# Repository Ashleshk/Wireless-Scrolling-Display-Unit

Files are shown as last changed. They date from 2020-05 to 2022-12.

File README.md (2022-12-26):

# Wireless-Scrolling-Display-Unit
 This project was buit for Academic Evaluation of term work for the Third year Mini Project  building in the subject of Electronic Sensor & Mini-Project in Course of E&TC 

## Working Project
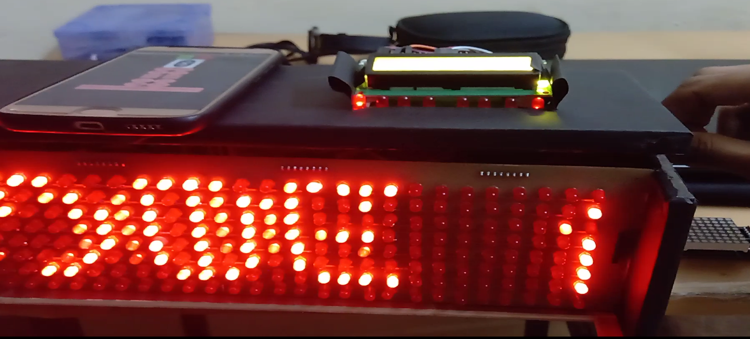
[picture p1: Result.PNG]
Result


## Won Project Exhibition Competition 
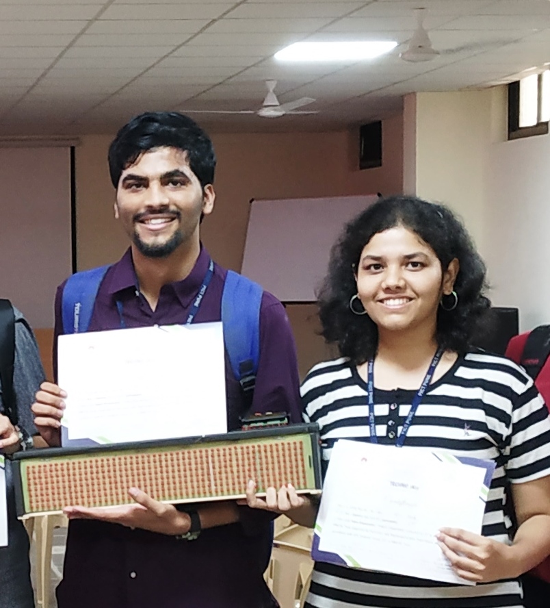
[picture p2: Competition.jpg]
Achivement


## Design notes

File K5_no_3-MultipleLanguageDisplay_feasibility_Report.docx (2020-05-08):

Title : Multiple Language Display Unit (Wireless Display Unit)

……………………………………………………………………………………………………………………………………………………………..

Group members: 1) Ashlesh Khajbage ………………2) Aditi Dorle …………………………………………………

3) Akhil Rane …………..……………………………………. 4)…………………………………………………………………….

Tools required | Testing possibility | Controller | Cost
Hardware/components LEDs Bluetooth Module / ESP2866 MAX7219 Resistors Perforated Board | Hardware Yes Yes Yes Yes No(unless clock input req) No No | Arduino Or PIC18F4550 (whichever support communication feasible) | ESP2866 – 200/- Boards,LEDs- 260/- MAX7219(6) -1080/- Resistors -6/- SolderingWire-80/- Wire -36/-
Software - MATLAB IDE - Arduino IDE - Proteus - Eagle - Fusion 360 | Software Yes yes yes yes (at least on 1 pc)
Tools available within campus or outside | Sensors required | Signal conditioning if any
-Soldering gun -dc power supply unit | -nil | -3.3V signal Conditioning OR -separate power supply | - 50/-
Applications if any | PCB design and fabrication | Datasheets/ application notes available
- Railway stations, - Airports - Colleges And Schools - Bus-stops and any other public places. - Public transport | - Controller circuit - Led Matrix - Power supply (5V and 3.3V) - Daughter Board | - Arduino/PIC18F - Decade counter(4017) - Transistors (2N3904) - MAX7219 | Estimated Cost Led matrix -1500/- Max-driver – 360/- Arduino board- 400/-
Mechanical design | Enclosure design | Demonstration
- Rectangular Box Signature of Guide | - Wooden Enclosure

Pune Institute of Computer technology, Pune Department of Electronics and Telecommunication T. E Mini project feasibility study sheet Sem-II 2018-19

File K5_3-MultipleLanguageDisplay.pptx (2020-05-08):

## Pune Institute of Computer Technology, Pune Dept. of E&TC

304196: Employability Skills and Mini Project (ESMP)
(2015 Course)

“MULTIPLE LANGUAGE
DISPLAY UNIT”

Guided By: Dr. R.Sreemathy

By:
1) ADITI DORLE (3503)
2) AKHIL RANE(3506)
3) ASHLESH KHAJBAGE(3508)

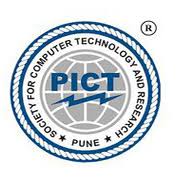
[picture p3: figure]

## Block Schematic

TE <Class>

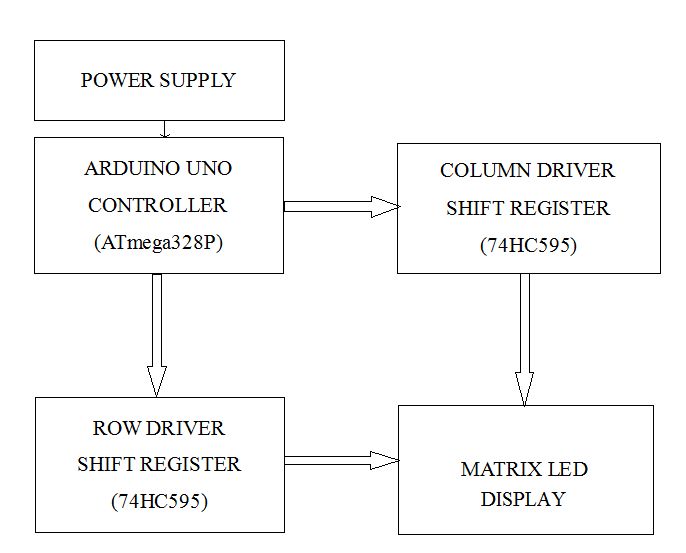
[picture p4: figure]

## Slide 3

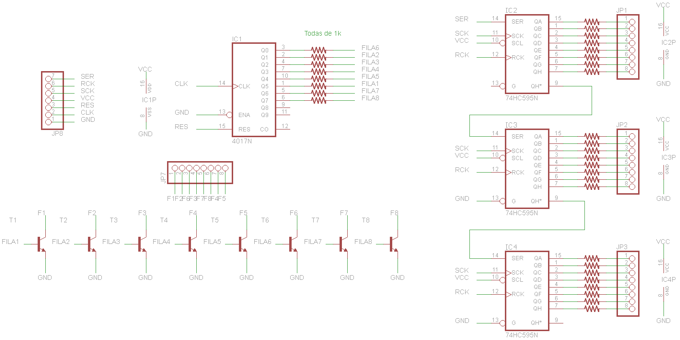
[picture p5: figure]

## resources Required

- 144 RED LEDs.
- 24 Resistors
- 4017 Decade Counter
- 6 1k-Resistances
- 6 2N3904 Transistors
- A Long Perf Board
- Arduino356
- 3 74HC595 shift register
- Some pin headers

## Working model Animation

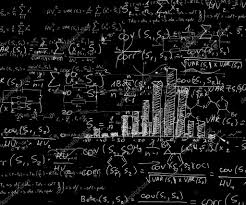
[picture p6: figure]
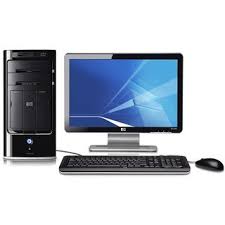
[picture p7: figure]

Input: Satyamev Jayte

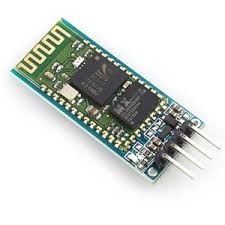
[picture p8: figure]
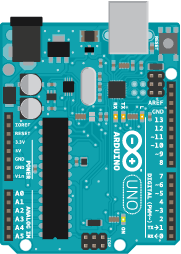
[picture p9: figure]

Satyamev Jayte

सत्यमेव जयते

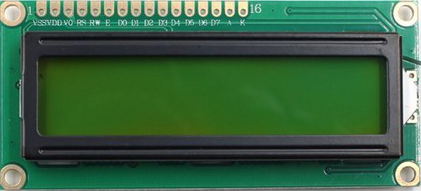
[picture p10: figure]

String recieving

Bluetooth device

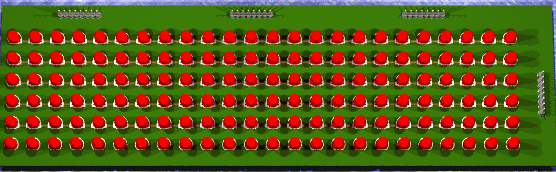
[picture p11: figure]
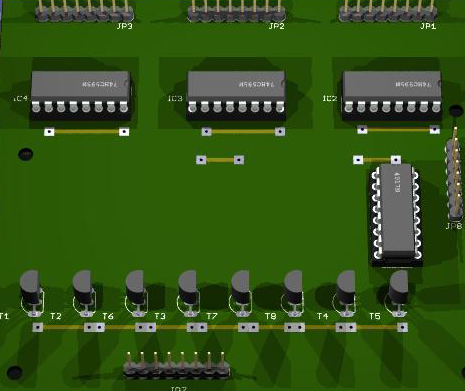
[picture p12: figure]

Connected

Satyamev Jayte

सत्यमेव जयते

## Features, future Scope

- This project focuses on displaying messages of multiple languages.
- It is cost effective.
- Easy to build.
- It can be used in
  - Railway stations,
  - Airports
  - Colleges And Schools
  - Bus-stops and any other public places.
  - Public transport

## References

- Research paper:
  - Design & Simulation of Moving Message Display using Microcontroller: Available from: https://www.researchgate.net/ (https://www.researchgate.net/publication/)
publication/ (https://www.researchgate.net/publication/)[Accessed: 10th May 2010]
- Website References:
  - Electronics LAB, Santi Rodríguez: 24x6 led matrix control unit[online]. Available from: http://www.electronics-lab.com/project/24x6-led-matrix-control-circuit/ (http://www.electronics-lab.com/project/24x6-led-matrix-control-circuit/)
  - Intructables, karthimech09 (https://www.instructables.com/member/karthimech09/) : 48x8 Scrolling matrix Display using arduino [online]. Available from: https://www.instructables.com/id/Make-a-24X6-LED-matrix/

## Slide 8

Thanks

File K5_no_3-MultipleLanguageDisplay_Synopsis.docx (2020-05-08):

Employability Skills& Mini Project
Class & Batch | | : | TE-5; K5 | | Group No. | | : | 3

Synopsis

on

“MULTIPLE LANGUAGE DISPLAY UNIT”

Submitted By
Roll No. | Name of the Student | | | e-mail id | | Mobile No.
3503 | Aditi Dorle | | | dorle.aditi@gmail.com | | 7743876151
3506 | Akhil Rane | | | ar.federer@gmail.com | | 9604780239
3508 | Ashlesh Khajbage | | | ashleshuk@gmail.com | | 9168003015

Project Guide:

Dr. R. Sreemati

DEPARTMENT OF ELECTRONICS AND TELECOMMUNICATIONS

PUNE INSTITUTE OF COMPUTER TECHNOLOGY

Academic Year : 2018 - 2019

1. Project Title: MULTIPLE LANGUAGE DISPLAY UNIT.

2. Introduction/ Motivation :

Why is the name board in railway stations written in three languages? As Railways falls under the Ministry of Railways of the Central Government, it follows the above two articles of the Constitution of India. Hence for the spread of Hindi as the Official Language (Raajbhasha), All stations display name boards in three languages i.e. English, Hindi and the official language of the state. The Same is with the case of bus stations, airports, locals trains, and buses etc. the displays used to announce the arrival and departure of a particular train, bus. There are many such displays used at a time on these stations. These displays are also used to display various other important messages like if someone’s missing if anyone has lost their belongings, which part of the stations the entire schedule can be seen, etc. Hence, such displays are usually called PLATFORM DISPLAYS.

These displays are mainly made up of an LED- matrix. The LED-matrix consists of many LEDs grouped together to form a matrix and is controlled through a control unit and a controller. This matrix mainly displays the messages pre-stored or short messages which can be instantly displayed from an interface for a certain amount of time. The led-matrix can be of 24x8 LEDs. It will be a sliding display, which will display words or messages (characters and numbers) in Hindi or English language.

3. Literature Survey / Prior work :

In earlier times when bus and railway stations were not developed and people had to find out time and wait hours for their buses and trains to arrive. There used to be pre-scheduled printed boards of arrival and departure of trains and buses. Then there used to be simple announcements through microphones and loudspeakers explaining the time of arrival and departure or the delay of the trains. Also, the driver has to yell about the next stop. But as the technology grew, platform displays came into existence. People could now read as to when their train will arrive. Since there are people from different linguistic backgrounds in India, there is a need for multiple language displays. The first platform displays were set in Britain and later on adapted worldwide. This project is just an extension of platform displays with additional benefits.

4. Problem Definition and Objectives :

The project will consist of an LED-MATRIX (24X8) which will be used to display the short and concise messages. The LED-MATRIX will be controlled using a control circuit/module and a controller. The major objective of this project is that in a place like India, where different people speak and understand different languages we need to account to their needs. The messages are after all displayed for the people’s benefit. So, everyone should be able to understand displayed messages easily, hence this concept of different language display.

5. Objectives :

1. Multiple languages to be displayed: Hindi, English.

2. Self-made LED MATRIX.

3. 24x8 LED MATRIX

1.Block Diagram :


1. Power Supply - Through the Power Supply, we'll provide 5V and 3.3V for the microcontroller board and communication module that may be wifi module or a Bluetooth module.

2. PIC microcontroller- The PIC stands for Peripheral Interface Controller. The microcontroller generates the output logic pulses so that the LED light is switched ON and OFF at certain intervals. The Crystal interfaced to the input pins of the microcontroller provides accurate clock signals at the crystal frequency.

3.Control Unit-The circuit is able to drive a 24×8 LED matrix using an external Microcontroller. Control signals can be easily generated by a microcontroller.

4 LED Matrix- In a dot matrix display, multiple LEDs are wired together in rows and columns. This is done to minimize the number of pins required to drive them. For example, an 8×8 matrix of LEDs (shown below) would need 64 I/O pins, one for each LED pixel. By wiring all the anodes together in rows (R1 through R8), and cathodes in columns (C1 through C8), the required number of I/O pins is reduced to 16. Each LED is addressed by its row and column number.

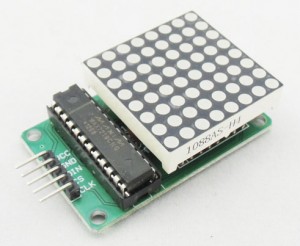
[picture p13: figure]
Pre-wired MAX 7219 and 8 x 8 LED matrix
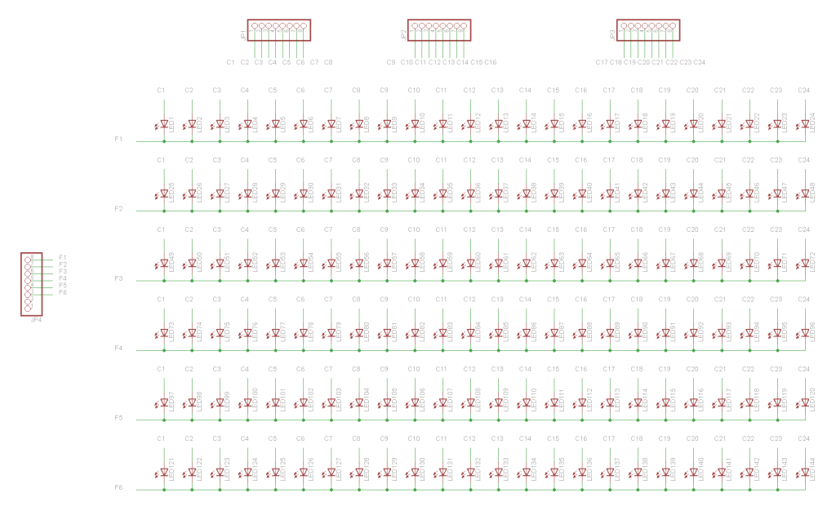
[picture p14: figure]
LED_board_schematic

2. Hardware Requirements:
1. LEDS
2. SHIFT REGISTERS
3. RESISTORS
4. DECADE COUNTERS
5. WIFI / BLUETOOTH MODULE
6. DC POWER SUPPLY
7. MICROCONTROLLER
8. USB-to-SERIAL CONVERTER
3. Software Requirements:
1. MPLAB/ARDUINO/PUTTY
2. PROTEUS
3. EAGLE
4. References
i. Electronics LAB, Santi Rodríguez: 24x6 led matrix control unit[online]. Available from: http://www.electronics-lab.com/project/24x6-led-matrix-control-circuit/
ii. Intructables, karthimech09 (https://www.instructables.com/member/karthimech09/) : 48x8 Scrolling matrix Display using arduino [online]. Available from: (http://www.electronics-lab.com/project/24x6-led-matrix-control-circuit/) https://www.instructables.com/id/Make-a-24X6-LED-matrix/

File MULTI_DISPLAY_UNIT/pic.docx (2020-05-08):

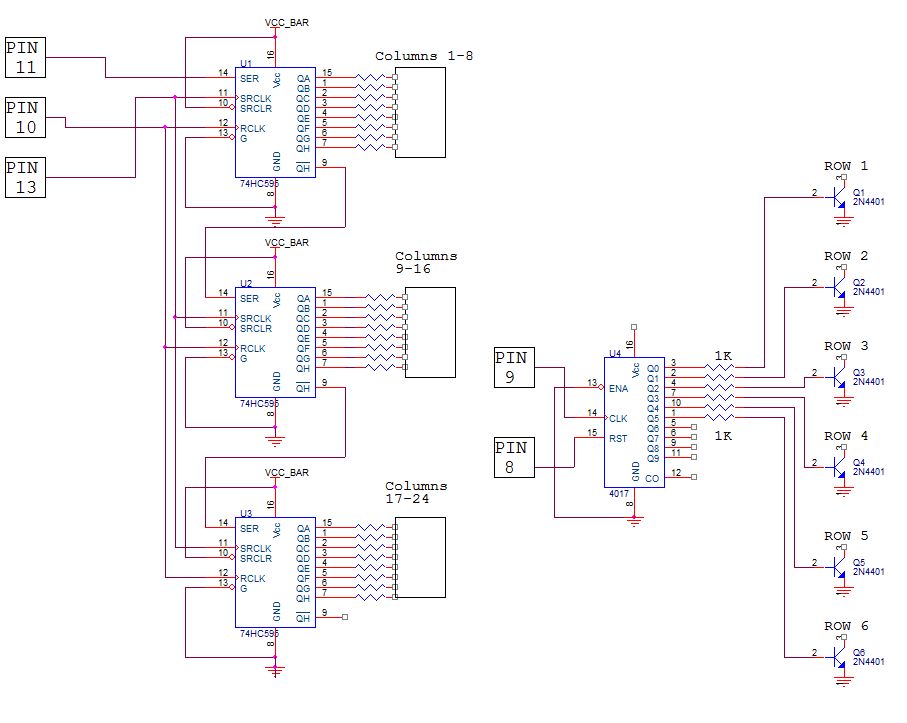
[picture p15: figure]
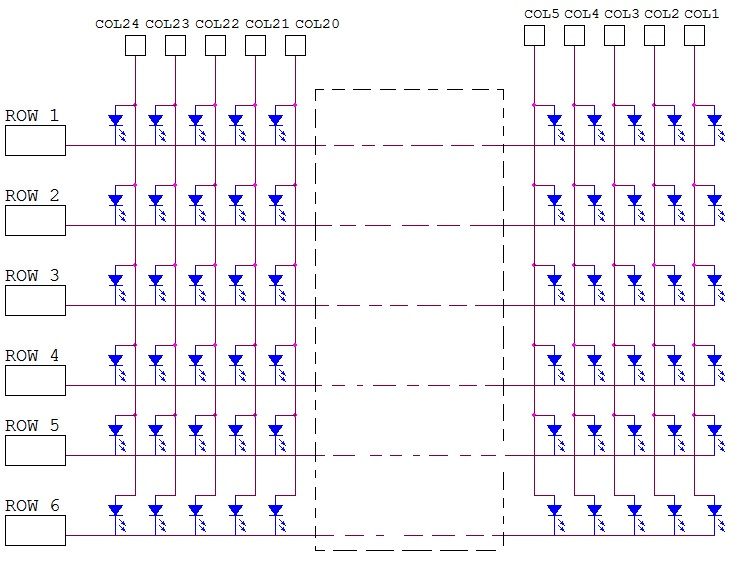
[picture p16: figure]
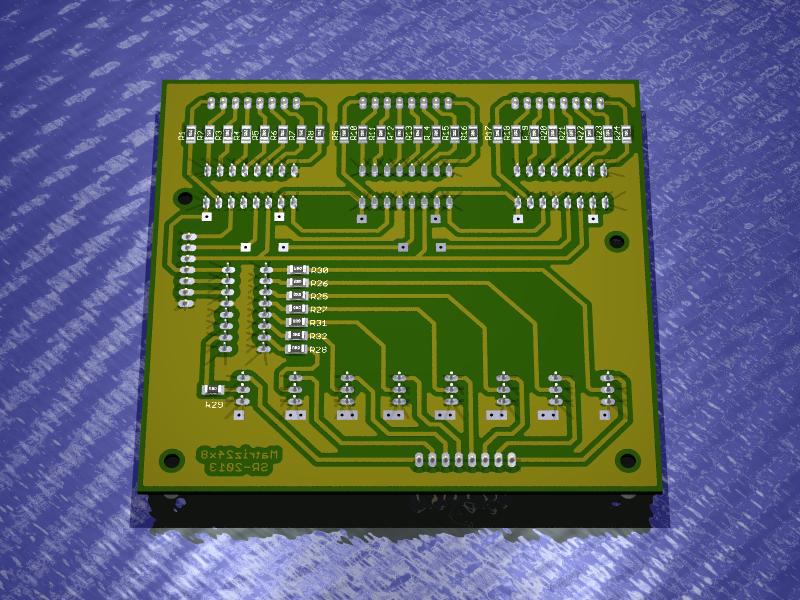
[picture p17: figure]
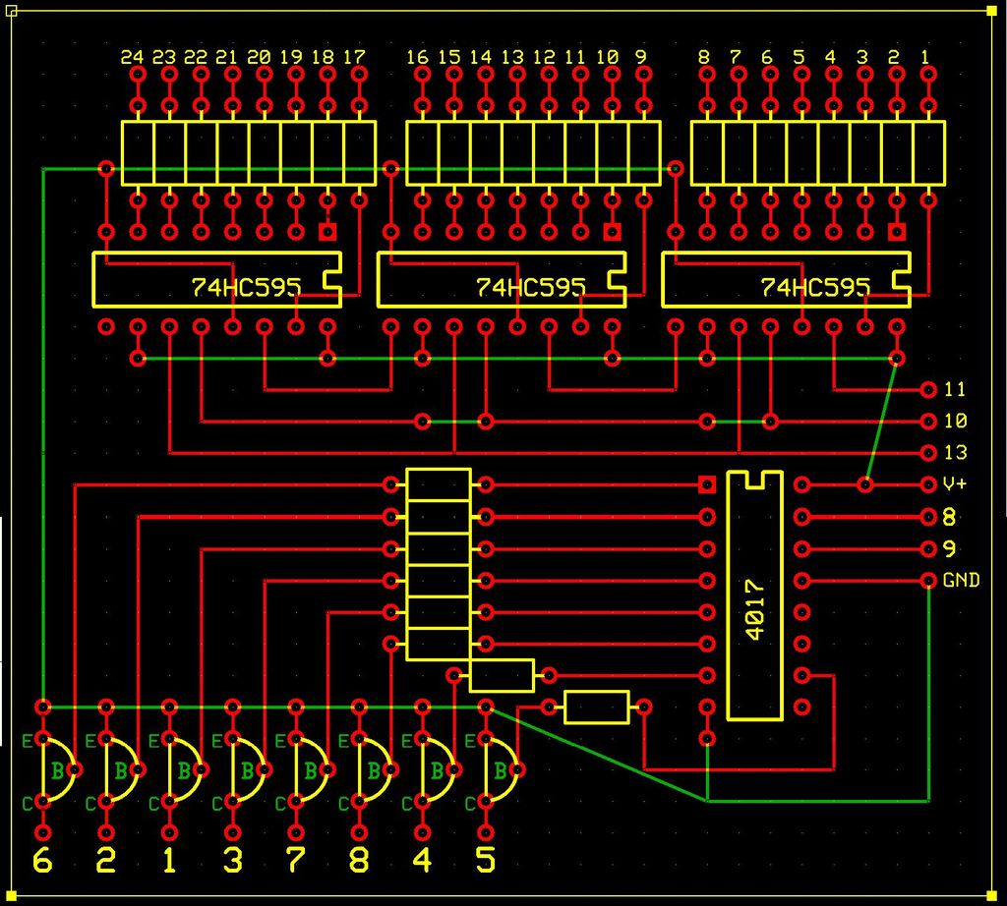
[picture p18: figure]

267.97 x 83.82mm and control board size: 100.33 x 93.65mm

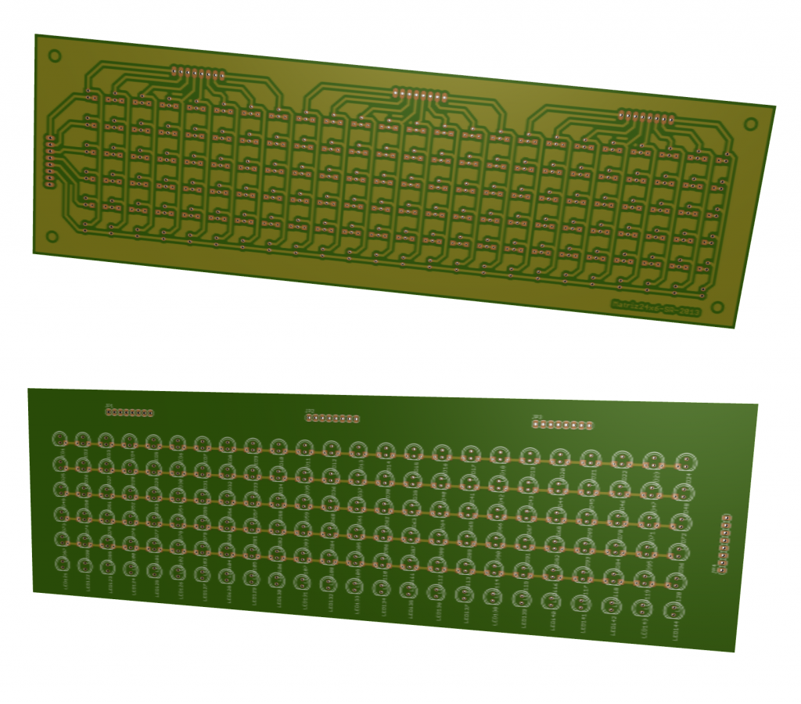
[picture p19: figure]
3D_LED_board_PCB
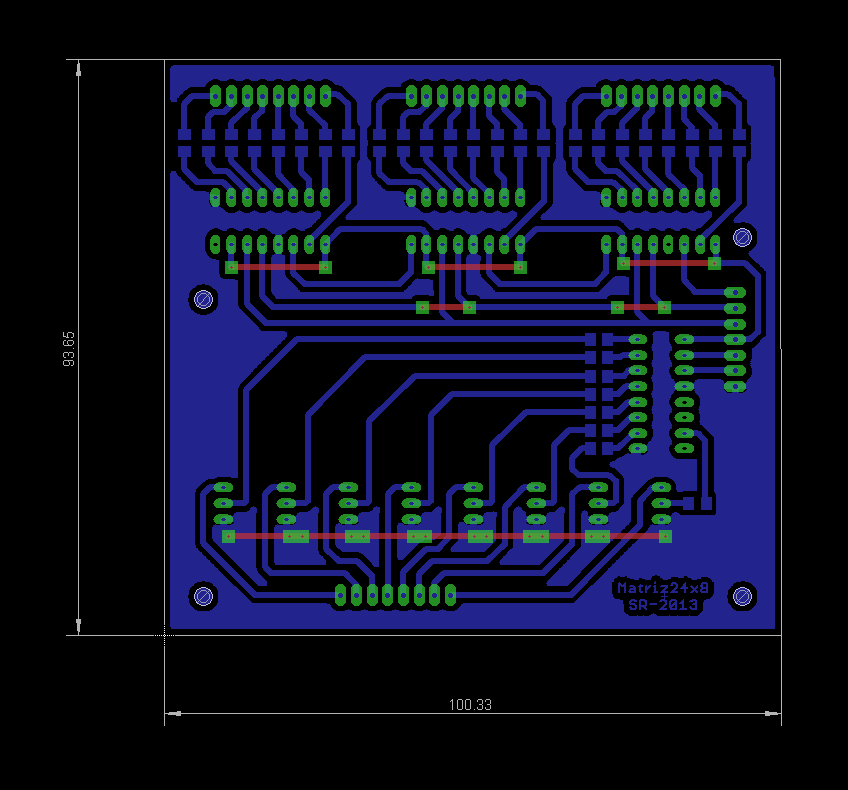
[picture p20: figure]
LED_board_schematic
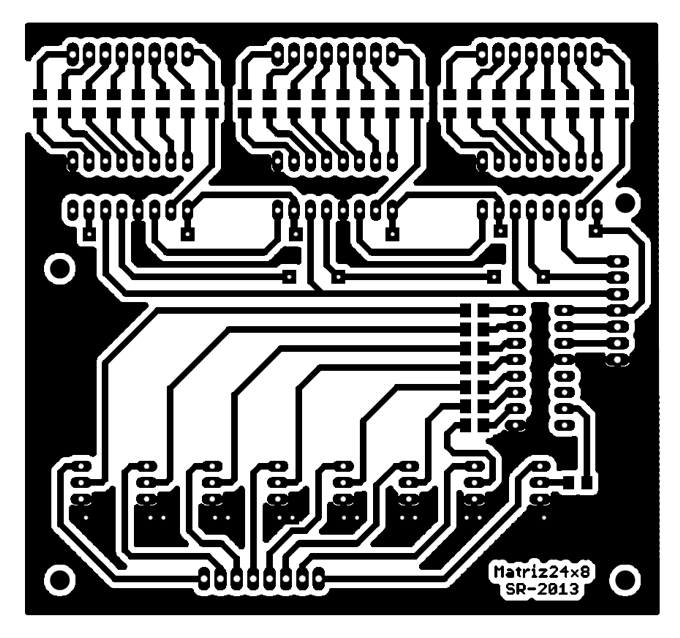
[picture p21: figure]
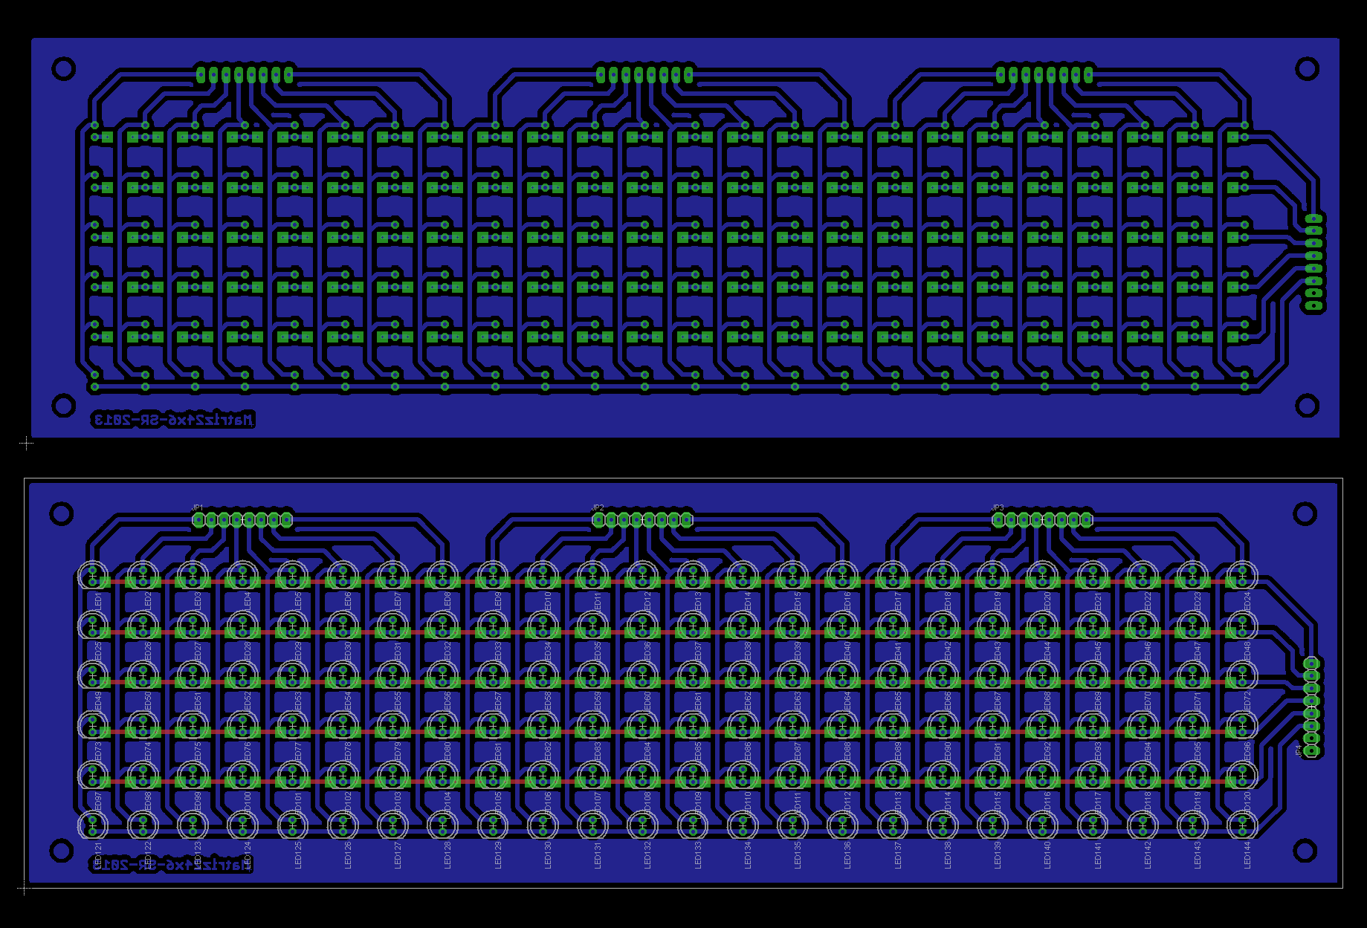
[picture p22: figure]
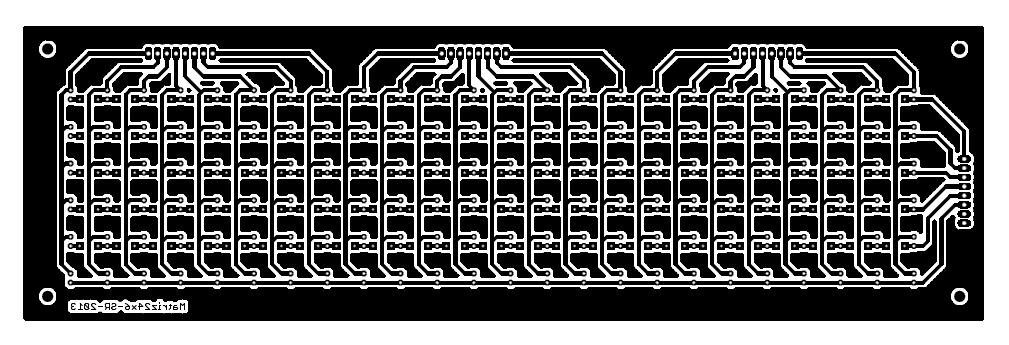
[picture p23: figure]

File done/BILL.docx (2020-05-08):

Sr. No | Component Name | Quantity | Per Unit Cost | Cost (Rupees)
1 | ATMEGA 328 PU | 1 | 300 | 300
2 | LEDS | 500 | 0.8 | 400
3 | PERF BOARD | 2 | 50 | 100
4 | SOLDER WIRE | 1 | 80 | 80
5 | WIRE | 15 | 5 | 75
6 | PINHEADS | 4 | 20 | 81
7 | MAX 7219 | 6 | 180 | 1080
8 | Capacitor 22uF | 2 | 10 | 20
9 | Capacitor 10uF | 2 | 15 | 30
10 | Capacitor disc | 3 | 10 | 30
11 | JUMPER WIRES | 2 | 80 | 160
12 | ATMEGA BASE | 1 | 10 | 10
13 | RESISTOR 150 Ohm | 4 | 1 | 4
14 | RESISTOR 10k Ohm | 1 | 2 | 2
15 | CRYSTAL OSCILLATOR | 1 | 30 | 30
16 | LM 7805 | 2 | 30 | 60
17 | PCB Designing of LED MATRIX | 1 | 1500 | 1500
18 | PCB Designing of MAX Controller | 6 | 180 | 1080
19 | PCB Designing of Arduino | 1 | 384 | 384
| | | TOTAL COST | 5624

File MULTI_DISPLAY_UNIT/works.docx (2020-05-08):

#define BA {B01110000,B10001000,B10001000,B11111000,B10001000,B10001000}

#define BB {B11110000,B10001000,B10001000,B11110000,B10001000,B11111000}

#define BC {B11111000,B10000000,B10000000,B10000000,B10000000,B11111000}

#define BD {B11110000,B10001000,B10001000,B10001000,B10001000,B11110000}

#define BE {B11111000,B10000000,B10000000,B11110000,B10000000,B11111000}

#define BF {B11111000,B10000000,B10000000,B11110000,B10000000,B10000000}

#define BG {B01110000,B10001000,B10000000,B10011000,B10001000,B01110000}

#define BH {B10001000,B10001000,B11111000,B10001000,B10001000,B10001000}

#define BI {B11111000,B00100000,B00100000,B00100000,B00100000,B11111000}

#define BJ {B00111000,B00010000,B00010000,B00010000,B10010000,B01100000}

#define BM {B10001000,B11011000,B10101000,B10101000,B10001000,B10001000}

#define BN {B10001000,B11001000,B10101000,B10101000,B10011000,B10001000}

#define BL {B10000000,B10000000,B10000000,B10000000,B10000000,B11111000}

#define BO {B01110000,B10001000,B10001000,B10001000,B10001000,B01110000}

#define BP {B11110000,B10001000,B10001000,B11110000,B10000000,B10000000}

#define BQ {B01110000,B10001000,B10101000,B10011000,B01111000,B00001000}

#define BR {B11110000,B10001000,B10001000,B11110000,B10001000,B10001000}

#define BS {B01110000,B10001000,B01100000,B00010000,B10001000,B01110000}

#define BK {B10001000,B10010000,B11100000,B11100000,B10010000,B10001000}

#define BT {B11111000,B00100000,B00100000,B00100000,B00100000,B00100000}

#define BU {B10001000,B10001000,B10001000,B10001000,B10001000,B01110000}

#define BV {B10001000,B10001000,B10001000,B10001000,B01010000,B00100000}

#define BW {B10001000,B10001000,B10101000,B10101000,B10101000,B01010000}

#define BX {B10001000,B01010000,B00100000,B00100000,B01010000,B10001000}

#define BY {B10001000,B01010000,B00100000,B00100000,B00100000,B00100000}

#define BZ {B11111000,B00001000,B00110000,B01100000,B10000000,B11111000}

#define LA{B00000000,B01110000,B00001000,B01111000,B10001000,B01111000}

#define LB{B10000000,B10000000,B10110000,B11001000,B10001000,B11110000}

#define LC{B00000000,B01110000,B10000000,B10000000,B10001000,B01110000}

#define LD{B00001000,B00001000,B01111000,B10001000,B10001000,B01111000}

#define LE{B00000000,B01110000,B10001000,B11111000,B10000000,B01110000}

#define LF{B00110000,B01001000,B01000000,B11100000,B01000000,B01000000}

#define LG{B00000000,B01111000,B10001000,B01111000,B00001000,B01110000}

#define LH{B10000000,B10000000,B10110000,B11001000,B10001000,B10001000}

#define LI{B00100000,B00000000,B01100000,B00100000,B00100000,B01111000}

#define LJ{B00010000,B00000000,B00111000,B00010000,B10010000,B01100000}

#define LK{B10000000,B10010000,B10100000,B11000000,B10100000,B10010000}

#define LL{B01100000,B00100000,B00100000,B00100000,B00100000,B01111000}

#define LM{B00000000,B00000000,B11010000,B10101000,B10101000,B10001000}

#define LN{B00000000,B00000000,B10110000,B11001000,B10001000,B10001000}

#define LO{B00000000,B01110000,B10001000,B10001000,B10001000,B01110000}

#define LP{B00000000,B11110000,B10001000,B11110000,B10000000,B10000000}

#define LQ{B00000000,B01101000,B10011000,B01111000,B00001000,B00001000}

#define LR{B00000000,B00000000,B10110000,B11001000,B10000000,B10000000}

#define LS{B00000000,B01110000,B10000000,B01110000,B00001000,B11110000}

#define LT{B01000000,B01000000,B11100000,B01000000,B01001000,B00110000}

#define LU{B00000000,B00000000,B10001000,B10001000,B10011000,B01101000}

#define LV{B00000000,B00000000,B10001000,B10001000,B01010000,B00100000}

#define LW{B00000000,B00000000,B10001000,B10101000,B10101000,B01010000}

#define LX{B00000000,B10001000,B01010000,B00100000,B01010000,B10001000}

#define LY{B00000000,B10001000,B10001000,B01111000,B00001000,B01110000}

#define LZ{B00000000,B11111000,B00010000,B00100000,B01000000,B11111000}

#define SPACE{B00000000,B00000000,B00000000,B00000000,B00000000,B00000000}

#define NUM0{B01110000,B10011000,B10101000,B10101000,B11001000,B01110000}

#define NUM1{B00100000,B01100000,B10100000,B00100000,B00100000,B01110000}

#define NUM2{B01110000,B10001000,B00001000,B01110000,B10000000,B11111000}

#define NUM3{B11110000,B00001000,B00001000,B01111000,B00001000,B11110000}

#define NUM4{B10001000,B10001000,B10001000,B11111000,B00001000,B00001000}

#define NUM5{B11111000,B10000000,B11110000,B00001000,B10001000,B01110000}

#define NUM6{B11111000,B10000000,B11111000,B10001000,B10001000,B11111000}

#define NUM7{B11111000,B00001000,B00001000,B01111000,B00001000,B00001000}

#define NUM8{B11111000,B10001000,B11111000,B10001000,B10001000,B11111000}

#define NUM9{B11111000,B10001000,B11111000,B00001000,B00001000,B11111000}

#define DEVIDE{B00001000,B00010000,B00100000,B00100000,B01000000,B10000000}

#define TWODOTS{B01100000,B01100000,B00000000,B00000000,B01100000,B01100000}

#define DOT{B00000000,B00000000,B00000000,B00000000,B01100000,B01100000}

#define COMA{B00000000,B00000000,B00000000,B00110000,B00110000,B01100000}

#define LINE{B00000000,B00000000,B11111000,B11111000,B00000000,B00000000}

#define QUASTION{B01110000,B10001000,B00010000,B00100000,B00000000,B00100000}

#define MARK{B00100000,B01110000,B01110000,B00100000,B00000000,B00100000}

int latchPin = 10;

int clockPin = 13;

int dataPin = 11;

int clock = 9;

int Reset = 8;

int latchPinPORTB = latchPin - 8;

int clockPinPORTB = clockPin - 8;

int dataPinPORTB = dataPin - 8;

int i = 0;

int incomingByte[44];

long scrolling_word[6];

int array_turn=0;

byte patterns[100][6];

byte dummy_array[70][6] ={BA,BB,BC,BD,BE,BF,BG,BH,BI,BJ,BK,BL,BM,BN,BO,BP,BQ,BR,BS,BT,BU,BV,BW,BX,BY,BZ,SPACE,NUM0,NUM1,NUM2,NUM3,NUM4,NUM5,NUM6,NUM7,NUM8,NUM9,DEVIDE,TWODOTS,DOT,COMA,LINE,QUASTION,MARK,LA,LB,LC,LD,LE,LF,LG,LH,LI,LJ,LK,LL,LM,LN,LO,LP,LQ,LR,LS,LT,LU,LV,LW,LX,LY,LZ};

void setup(){

Serial.begin(9600);

pinMode(dataPin,OUTPUT);

pinMode(clockPin,OUTPUT);

pinMode(latchPin,OUTPUT);

pinMode(clock,OUTPUT);

pinMode(Reset,OUTPUT);

digitalWrite(Reset,HIGH);

digitalWrite(Reset,LOW);

setupSPI();

}

void display_word(int loops,byte word_print[][6],int num_patterns,int delay_langth){// this function displays your symbols

i = 0;// resets the counter fot the 4017

for(int g=0;g<6;g++)//resets the the long int where your word goes

scrolling_word[g] = 0;

for(int x=0;x<num_patterns;x++){//main loop, goes over your symbols

// you will need to find a better way to make the symbols scroll my way is limited for 24 columns

for(int r=0;r<6;r++)//puts the buildes the first symbol

scrolling_word[r] |= word_print[x][r];

for (int z=0;z<6;z++){//the sctolling action

for(int p=0;p<6;p++)

scrolling_word[p] = scrolling_word[p] << 1;

// end of the scrolling funcion

for(int t=0;t<delay_langth;t++){// delay function, it just loops over the same display

for(int y=0;y<6;y++){// scaning the display

if(i == 6){// counting up to 6 with the 4017

digitalWrite(Reset,HIGH);

digitalWrite(Reset,LOW);

i = 0;

}

latchOff();

spi_transfer(make_word(0x01000000,y));// sending the data

spi_transfer(make_word(0x00010000,y));

spi_transfer(make_word(0x00000100,y));

latchOn();

delayMicroseconds(800);//waiting a bit

latchOff();

spi_transfer(0);// clearing the data

spi_transfer(0);

spi_transfer(0);

latchOn();

digitalWrite(clock,HIGH);//counting up with the 4017

digitalWrite(clock,LOW);

i++;

}

}

}

}

finish_scroll(delay_langth);

}

void finish_scroll(int delay_scroll){// this function is the same as the funcion above, it just finishing scrolling

for (int n=0;n<24;n++){

for(int h=0;h<6;h++)

scrolling_word[h] = scrolling_word[h] << 1;

for(int w=0;w<delay_scroll;w++){

for(int k=0;k<6;k++){

if(i == 6){

digitalWrite(Reset,HIGH);

digitalWrite(Reset,LOW);

i = 0;

}

latchOff();

spi_transfer(make_word(0x01000000,k));

spi_transfer(make_word(0x00010000,k));

spi_transfer(make_word(0x00000100,k));

latchOn();

delayMicroseconds(800);

latchOff();

spi_transfer(0);

spi_transfer(0);

spi_transfer(0);

latchOn();

digitalWrite(clock,HIGH);

digitalWrite(clock,LOW);

i++;

}

}

}

}

byte make_word (long posistion,byte turn){

byte dummy_word = 0;

for(int q=0;q<8;q++){

if(scrolling_word[turn] & (posistion<<q))

dummy_word |= 0x01<<q;

}

return dummy_word;

}

void loop() {

// send data only when you receive data:

if(Serial.available() > 0){

delay(100);

incomingByte[array_turn] = Serial.read();

array_turn++;

}

else{

if(array_turn != 0){

for(int az=0;az<array_turn;az++){

if((incomingByte[az] > 64 && incomingByte[az] < 91) || (incomingByte[az] > 96 && incomingByte[az] < 123)){

if(incomingByte[az] > 64 && incomingByte[az] < 91){

for(int lal=0;lal<6;lal++)

patterns[az][lal] = dummy_array[incomingByte[az] - 65][lal];

}

else{

for(int lal=0;lal<6;lal++)

patterns[az][lal] = dummy_array[incomingByte[az] - 53][lal];

}}

else{

switch(incomingByte[az]){

case 32://space

for(int lol=0;lol<6;lol++)

patterns[az][lol] = dummy_array[26][lol];

break;

case 33://mark

for(int lol=0;lol<6;lol++)

patterns[az][lol] = dummy_array[43][lol];

break;

case 45://line

for(int lol=0;lol<6;lol++)

patterns[az][lol] = dummy_array[41][lol];

break;

case 44://coma

for(int lol=0;lol<6;lol++)

patterns[az][lol] = dummy_array[40][lol];

break;

case 46://dot

for(int lol=0;lol<6;lol++)

patterns[az][lol] = dummy_array[39][lol];

break;

case 47://dvide

for(int lol=0;lol<6;lol++)

patterns[az][lol] = dummy_array[37][lol];

break;

case 48://0

for(int lol=0;lol<6;lol++)

patterns[az][lol] = dummy_array[27][lol];

break;

case 49://1

for(int lol=0;lol<6;lol++)

patterns[az][lol] = dummy_array[28][lol];

break;

case 50://2

for(int lol=0;lol<6;lol++)

patterns[az][lol] = dummy_array[29][lol];

break;

case 51://3

for(int lol=0;lol<6;lol++)

patterns[az][lol] = dummy_array[30][lol];

break;

case 52://4

for(int lol=0;lol<6;lol++)

patterns[az][lol] = dummy_array[31][lol];

break;

case 53://5

for(int lol=0;lol<6;lol++)

patterns[az][lol] = dummy_array[32][lol];

break;

case 54://6

for(int lol=0;lol<6;lol++)

patterns[az][lol] = dummy_array[33][lol];

break;

case 55://7

for(int lol=0;lol<6;lol++)

patterns[az][lol] = dummy_array[34][lol];

break;

case 56://8

for(int lol=0;lol<6;lol++)

patterns[az][lol] = dummy_array[35][lol];

break;

case 57://9

for(int lol=0;lol<6;lol++)

patterns[az][lol] = dummy_array[36][lol];

break;

case 58://tow dots

for(int lol=0;lol<6;lol++)

patterns[az][lol] = dummy_array[38][lol];

break;

case 63://quastion

for(int lol=0;lol<6;lol++)

patterns[az][lol] = dummy_array[42][lol];

break;

default:

for(int lol=0;lol<6;lol++)

patterns[az][lol] = dummy_array[26][lol];

break;

}

}

}

}

display_word(1,patterns,array_turn,15);

array_turn =0;

}

}

//display_word(1,patterns,43,15);// calls for the display_pattern function and says that int loop = 15(if you do more loop the pattern whould scrrol slower).

void latchOn(){

bitSet(PORTB,latchPinPORTB);

}

void latchOff(){

bitClear(PORTB,latchPinPORTB);

}

void setupSPI(){

byte clr;

SPCR |= ( (1<<SPE) | (1<<MSTR) ); // enable SPI as master

//SPCR |= ( (1<<SPR1) | (1<<SPR0) ); // set prescaler bits

SPCR &= ~( (1<<SPR1) | (1<<SPR0) ); // clear prescaler bits

clr=SPSR; // clear SPI status reg

clr=SPDR; // clear SPI data reg

SPSR |= (1<<SPI2X); // set prescaler bits

//SPSR &= ~(1<<SPI2X); // clear prescaler bits

delay(10);

}

byte spi_transfer(byte data)

{

SPDR = data; // Start the transmission

while (!(SPSR & (1<<SPIF))) // Wait the end of the transmission

{

};

return SPDR; // return the received byte, we don't need that

}

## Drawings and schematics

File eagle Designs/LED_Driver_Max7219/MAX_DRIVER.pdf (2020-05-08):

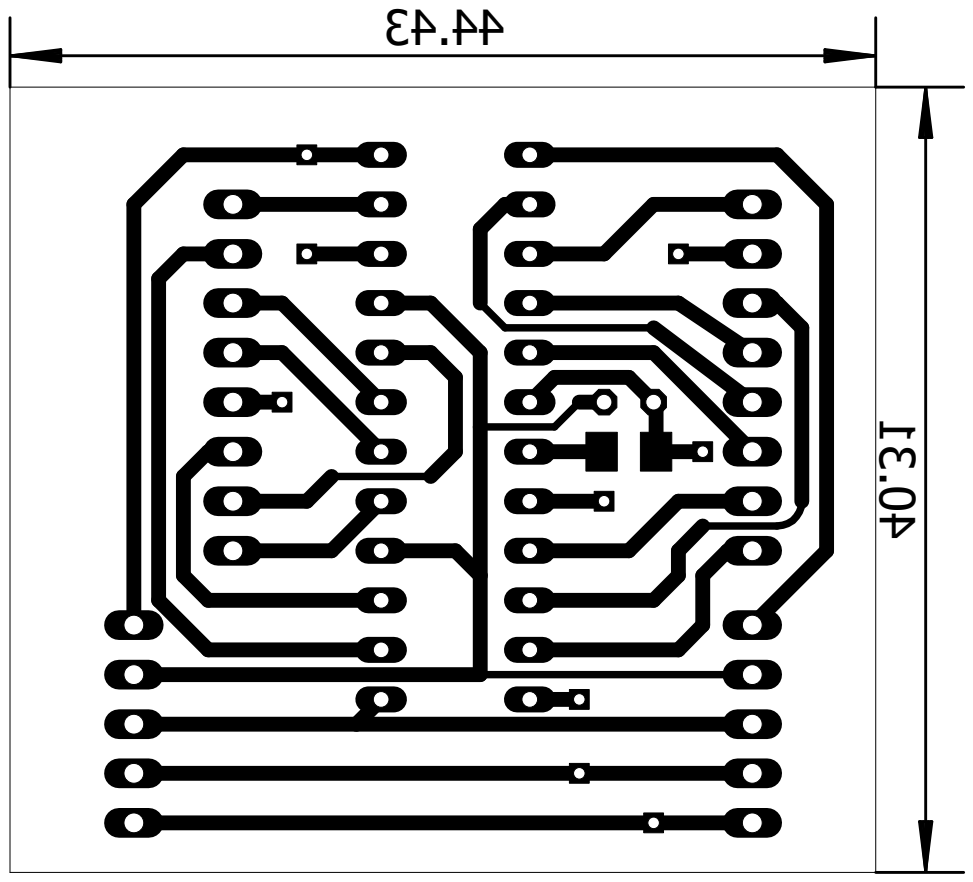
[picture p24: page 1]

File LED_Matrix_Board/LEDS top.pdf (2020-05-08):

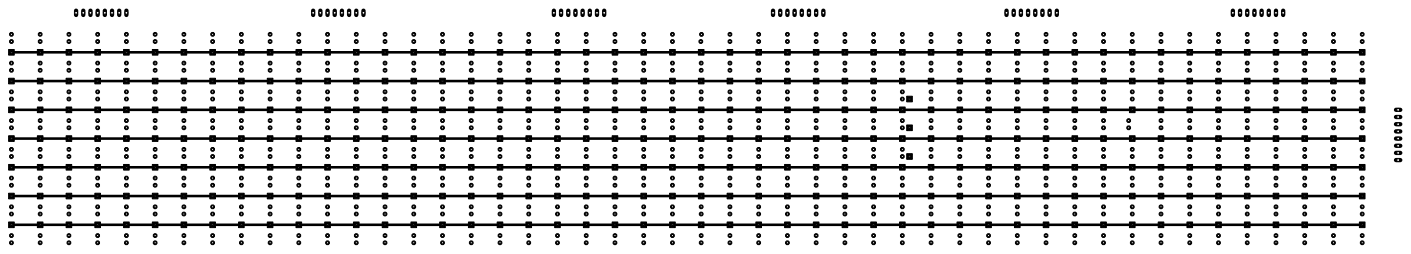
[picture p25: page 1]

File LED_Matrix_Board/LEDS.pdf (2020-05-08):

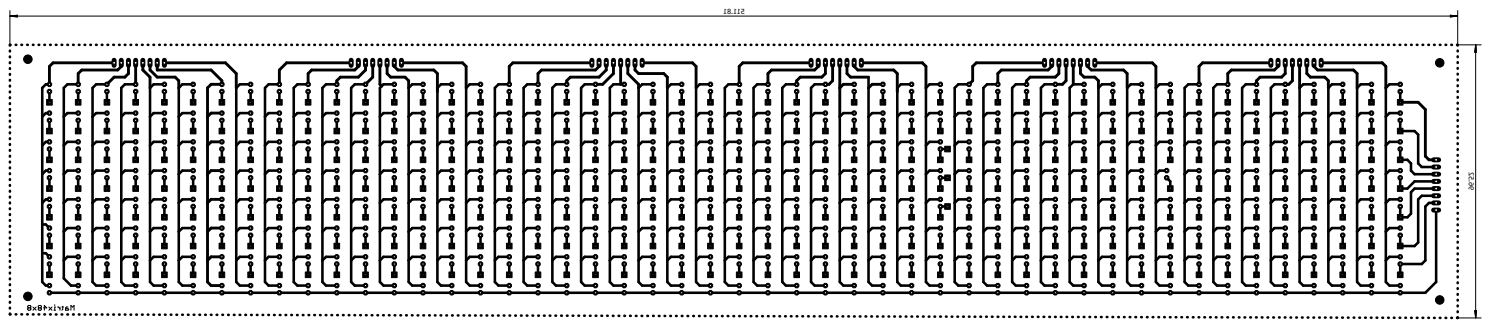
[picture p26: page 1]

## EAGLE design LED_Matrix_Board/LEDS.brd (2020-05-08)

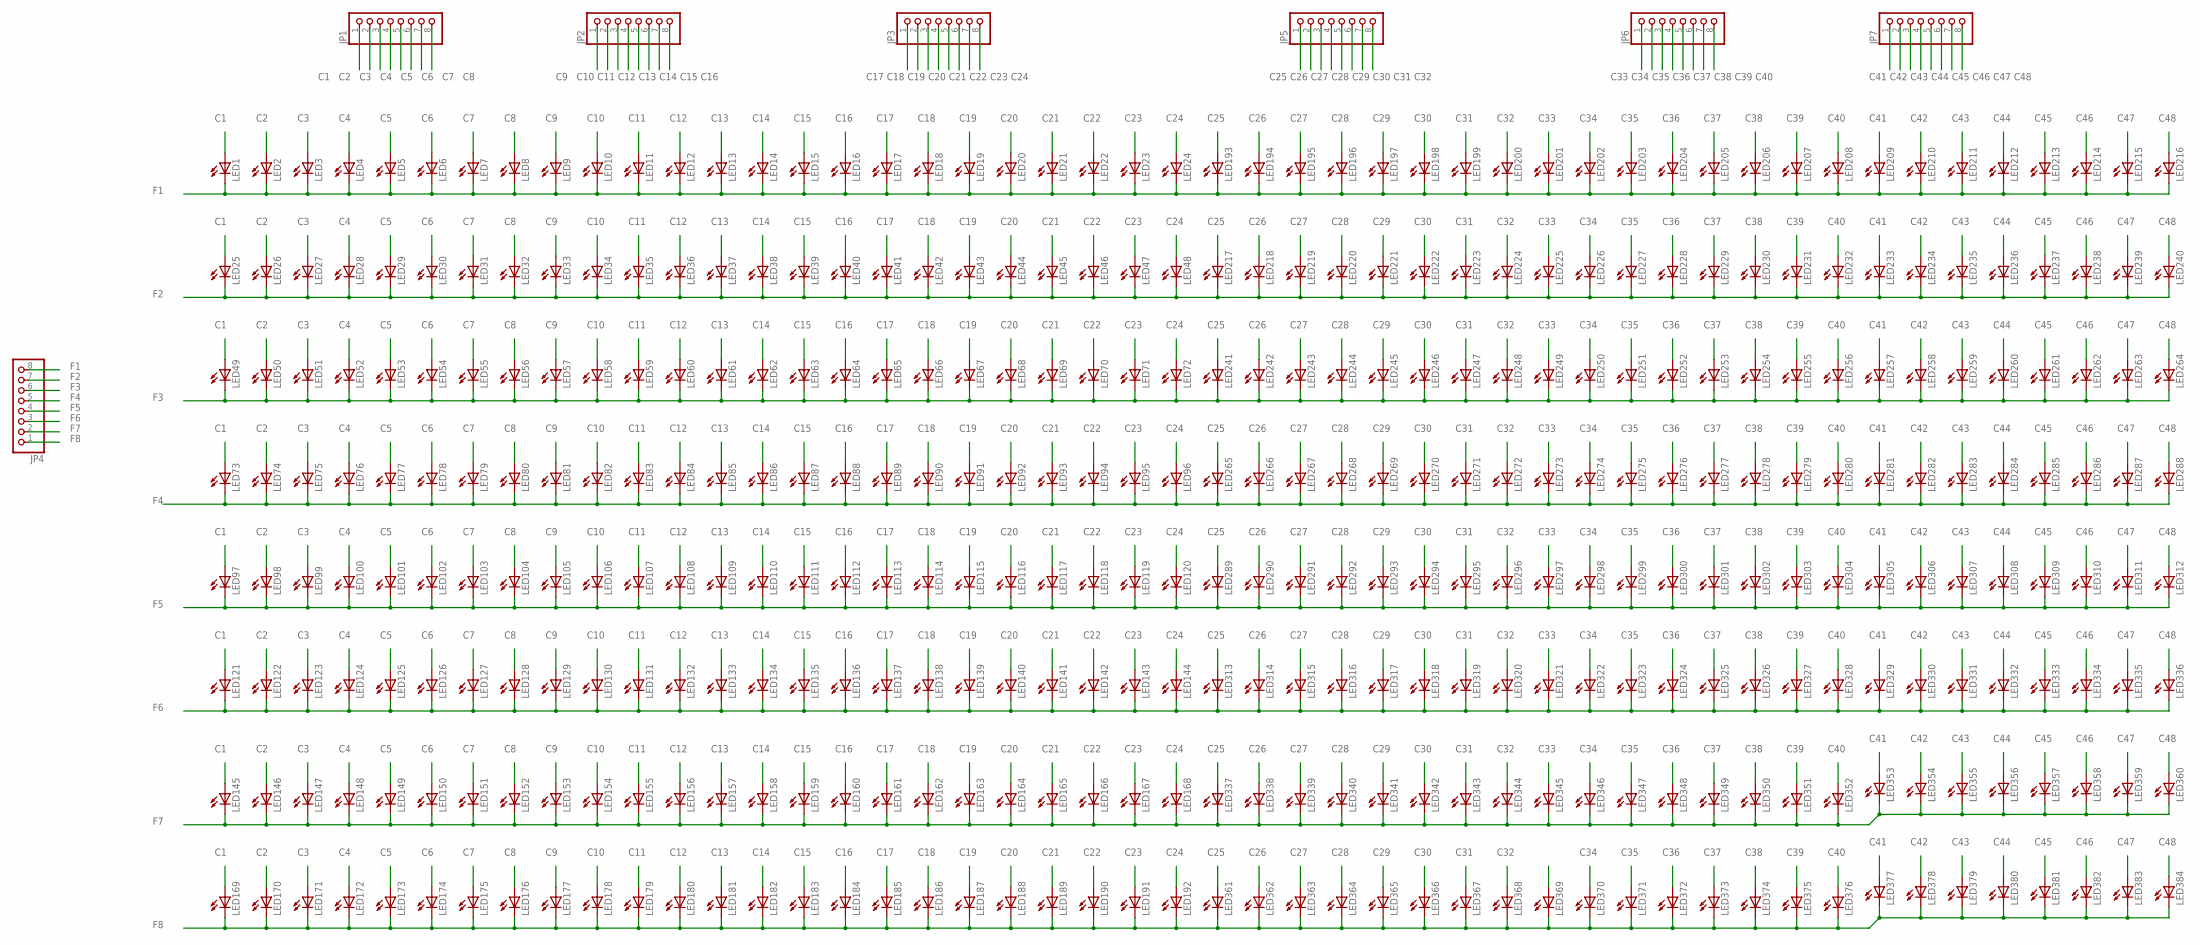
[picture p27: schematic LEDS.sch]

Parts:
JP1, JP2, JP3, JP4, JP5, JP6, JP7: PINHD-1X8; 1X08
LED1, LED2, LED3, LED4, LED5, LED6, LED7, LED8, LED9, LED10, LED11, LED12, LED13, LED14, LED15, LED16, LED17, LED18, LED19, LED20, LED21, LED22, LED23, LED24, LED25, LED26, LED27, LED28, LED29, LED30, LED31, LED32, LED33, LED34, LED35, LED36, LED37, LED38, LED39, LED40, LED41, LED42, LED43, LED44, LED45, LED46, LED47, LED48, LED49, LED50, LED51, LED52, LED53, LED54, LED55, LED56, LED57, LED58, LED59, LED60, LED61, LED62, LED63, LED64, LED65, LED66, LED67, LED68, LED69, LED70, LED71, LED72, LED73, LED74, LED75, LED76, LED77, LED78, LED79, LED80, LED81, LED82, LED83, LED84, LED85, LED86, LED87, LED88, LED89, LED90, LED91, LED92, LED93, LED94, LED95, LED96, LED97, LED98, LED99, LED100, LED101, LED102, LED103, LED104, LED105, LED106, LED107, LED108, LED109, LED110, LED111, LED112, LED113, LED114, LED115, LED116, LED117, LED118, LED119, LED120, LED121, LED122, LED123, LED124, LED125, LED126, LED127, LED128, LED129, LED130, LED131, LED132, LED133, LED134, LED135, LED136, LED137, LED138, LED139, LED140, LED141, LED142, LED143, LED144, LED145, LED146, LED147, LED148, LED149, LED150, LED151, LED152, LED153, LED154, LED155, LED156, LED157, LED158, LED159, LED160, LED161, LED162, LED163, LED164, LED165, LED166, LED167, LED168, LED169, LED170, LED171, LED172, LED173, LED174, LED175, LED176, LED177, LED178, LED179, LED180, LED181, LED182, LED183, LED184, LED185, LED186, LED187, LED188, LED189, LED190, LED191, LED192, LED193, LED194, LED195, LED196, LED197, LED198, LED199, LED200, LED201, LED202, LED203, LED204, LED205, LED206, LED207, LED208, LED209, LED210, LED211, LED212, LED213, LED214, LED215, LED216, LED217, LED218, LED219, LED220, LED221, LED222, LED223, LED224, LED225, LED226, LED227, LED228, LED229, LED230, LED231, LED232, LED233, LED234, LED235, LED236, LED237, LED238, LED239, LED240, LED241, LED242, LED243, LED244, LED245, LED246, LED247, LED248, LED249, LED250, LED251, LED252, LED253, LED254, LED255, LED256, LED257, LED258, LED259, LED260, LED261, LED262, LED263, LED264, LED265, LED266, LED267, LED268, LED269, LED270, LED271, LED272, LED273, LED274, LED275, LED276, LED277, LED278, LED279, LED280, LED281, LED282, LED283, LED284, LED285, LED286, LED287, LED288, LED289, LED290, LED291, LED292, LED293, LED294, LED295, LED296, LED297, LED298, LED299, LED300, LED301, LED302, LED303, LED304, LED305, LED306, LED307, LED308, LED309, LED310, LED311, LED312, LED313, LED314, LED315, LED316, LED317, LED318, LED319, LED320, LED321, LED322, LED323, LED324, LED325, LED326, LED327, LED328, LED329, LED330, LED331, LED332, LED333, LED334, LED335, LED336, LED337, LED338, LED339, LED340, LED341, LED342, LED343, LED344, LED345, LED346, LED347, LED348, LED349, LED350, LED351, LED352, LED353, LED354, LED355, LED356, LED357, LED358, LED359, LED360, LED361, LED362, LED363, LED364, LED365, LED366, LED367, LED368, LED369, LED370, LED371, LED372, LED373, LED374, LED375, LED376, LED377, LED378, LED379, LED380, LED381, LED382, LED383, LED384: LED5MM

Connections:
C1: JP1.1, LED1.A, LED25.A, LED49.A, LED73.A, LED97.A, LED121.A, LED145.A, LED169.A
C2: JP1.2, LED2.A, LED26.A, LED50.A, LED74.A, LED98.A, LED122.A, LED146.A, LED170.A
C3: JP1.3, LED3.A, LED27.A, LED51.A, LED75.A, LED99.A, LED123.A, LED147.A, LED171.A
C4: JP1.4, LED4.A, LED28.A, LED52.A, LED76.A, LED100.A, LED124.A, LED148.A, LED172.A
C5: JP1.5, LED5.A, LED29.A, LED53.A, LED77.A, LED101.A, LED125.A, LED149.A, LED173.A
C6: JP1.6, LED6.A, LED30.A, LED54.A, LED78.A, LED102.A, LED126.A, LED150.A, LED174.A
C7: JP1.7, LED7.A, LED31.A, LED55.A, LED79.A, LED103.A, LED127.A, LED151.A, LED175.A
C8: JP1.8, LED8.A, LED32.A, LED56.A, LED80.A, LED104.A, LED128.A, LED152.A, LED176.A
C9: JP2.1, LED9.A, LED33.A, LED57.A, LED81.A, LED105.A, LED129.A, LED153.A, LED177.A
C10: JP2.2, LED10.A, LED34.A, LED58.A, LED82.A, LED106.A, LED130.A, LED154.A, LED178.A
C11: JP2.3, LED11.A, LED35.A, LED59.A, LED83.A, LED107.A, LED131.A, LED155.A, LED179.A
C12: JP2.4, LED12.A, LED36.A, LED60.A, LED84.A, LED108.A, LED132.A, LED156.A, LED180.A
C13: JP2.5, LED13.A, LED37.A, LED61.A, LED85.A, LED109.A, LED133.A, LED157.A, LED181.A
C14: JP2.6, LED14.A, LED38.A, LED62.A, LED86.A, LED110.A, LED134.A, LED158.A, LED182.A
C15: JP2.7, LED15.A, LED39.A, LED63.A, LED87.A, LED111.A, LED135.A, LED159.A, LED183.A
C16: JP2.8, LED16.A, LED40.A, LED64.A, LED88.A, LED112.A, LED136.A, LED160.A, LED184.A
C17: JP3.1, LED17.A, LED41.A, LED65.A, LED89.A, LED113.A, LED137.A, LED161.A, LED185.A
C18: JP3.2, LED18.A, LED42.A, LED66.A, LED90.A, LED114.A, LED138.A, LED162.A, LED186.A
C19: JP3.3, LED19.A, LED43.A, LED67.A, LED91.A, LED115.A, LED139.A, LED163.A, LED187.A
C20: JP3.4, LED20.A, LED44.A, LED68.A, LED92.A, LED116.A, LED140.A, LED164.A, LED188.A
C21: JP3.5, LED21.A, LED45.A, LED69.A, LED93.A, LED117.A, LED141.A, LED165.A, LED189.A
C22: JP3.6, LED22.A, LED46.A, LED70.A, LED94.A, LED118.A, LED142.A, LED166.A, LED190.A
C23: JP3.7, LED23.A, LED47.A, LED71.A, LED95.A, LED119.A, LED143.A, LED167.A, LED191.A
C24: JP3.8, LED24.A, LED48.A, LED72.A, LED96.A, LED120.A, LED144.A, LED168.A, LED192.A
C25: JP5.1, LED193.A, LED217.A, LED241.A, LED265.A, LED289.A, LED313.A, LED337.A, LED361.A
C26: JP5.2, LED194.A, LED218.A, LED242.A, LED266.A, LED290.A, LED314.A, LED338.A, LED362.A
C27: JP5.3, LED195.A, LED219.A, LED243.A, LED267.A, LED291.A, LED315.A, LED339.A, LED363.A
C28: JP5.4, LED196.A, LED220.A, LED244.A, LED268.A, LED292.A, LED316.A, LED340.A, LED364.A
C29: JP5.5, LED197.A, LED221.A, LED245.A, LED269.A, LED293.A, LED317.A, LED341.A, LED365.A
C30: JP5.6, LED198.A, LED222.A, LED246.A, LED270.A, LED294.A, LED318.A, LED342.A, LED366.A
C31: JP5.7, LED199.A, LED223.A, LED247.A, LED271.A, LED295.A, LED319.A, LED343.A, LED367.A
C32: JP5.8, LED200.A, LED224.A, LED248.A, LED272.A, LED296.A, LED320.A, LED344.A, LED368.A
C33: JP6.1, LED201.A, LED225.A, LED249.A, LED273.A, LED297.A, LED321.A, LED345.A
C34: JP6.2, LED202.A, LED226.A, LED250.A, LED274.A, LED298.A, LED322.A, LED346.A, LED370.A
C35: JP6.3, LED203.A, LED227.A, LED251.A, LED275.A, LED299.A, LED323.A, LED347.A, LED371.A
C36: JP6.4, LED204.A, LED228.A, LED252.A, LED276.A, LED300.A, LED324.A, LED348.A, LED372.A
C37: JP6.5, LED205.A, LED229.A, LED253.A, LED277.A, LED301.A, LED325.A, LED349.A, LED373.A
C38: JP6.6, LED206.A, LED230.A, LED254.A, LED278.A, LED302.A, LED326.A, LED350.A, LED374.A
C39: JP6.7, LED207.A, LED231.A, LED255.A, LED279.A, LED303.A, LED327.A, LED351.A, LED375.A
C40: JP6.8, LED208.A, LED232.A, LED256.A, LED280.A, LED304.A, LED328.A, LED352.A, LED376.A
C41: JP7.1, LED209.A, LED233.A, LED257.A, LED281.A, LED305.A, LED329.A, LED353.A, LED369.A, LED377.A
C42: JP7.2, LED210.A, LED234.A, LED258.A, LED282.A, LED306.A, LED330.A, LED354.A, LED378.A
C43: JP7.3, LED211.A, LED235.A, LED259.A, LED283.A, LED307.A, LED331.A, LED355.A, LED379.A
C44: JP7.4, LED212.A, LED236.A, LED260.A, LED284.A, LED308.A, LED332.A, LED356.A, LED380.A
C45: JP7.5, LED213.A, LED237.A, LED261.A, LED285.A, LED309.A, LED333.A, LED357.A, LED381.A
C46: JP7.6, LED214.A, LED238.A, LED262.A, LED286.A, LED310.A, LED334.A, LED358.A, LED382.A
C47: JP7.7, LED215.A, LED239.A, LED263.A, LED287.A, LED311.A, LED335.A, LED359.A, LED383.A
C48: JP7.8, LED216.A, LED240.A, LED264.A, LED288.A, LED312.A, LED336.A, LED360.A, LED384.A
F1: JP4.8, LED1.K (C), LED2.K (C), LED3.K (C), LED4.K (C), LED5.K (C), LED6.K (C), LED7.K (C), LED8.K (C), LED9.K (C), LED10.K (C), LED11.K (C), LED12.K (C), LED13.K (C), LED14.K (C), LED15.K (C), LED16.K (C), LED17.K (C), LED18.K (C), LED19.K (C), LED20.K (C), LED21.K (C), LED22.K (C), LED23.K (C), LED24.K (C), LED193.K (C), LED194.K (C), LED195.K (C), LED196.K (C), LED197.K (C), LED198.K (C), LED199.K (C), LED200.K (C), LED201.K (C), LED202.K (C), LED203.K (C), LED204.K (C), LED205.K (C), LED206.K (C), LED207.K (C), LED208.K (C), LED209.K (C), LED210.K (C), LED211.K (C), LED212.K (C), LED213.K (C), LED214.K (C), LED215.K (C), LED216.K (C)
F2: JP4.7, LED25.K (C), LED26.K (C), LED27.K (C), LED28.K (C), LED29.K (C), LED30.K (C), LED31.K (C), LED32.K (C), LED33.K (C), LED34.K (C), LED35.K (C), LED36.K (C), LED37.K (C), LED38.K (C), LED39.K (C), LED40.K (C), LED41.K (C), LED42.K (C), LED43.K (C), LED44.K (C), LED45.K (C), LED46.K (C), LED47.K (C), LED48.K (C), LED217.K (C), LED218.K (C), LED219.K (C), LED220.K (C), LED221.K (C), LED222.K (C), LED223.K (C), LED224.K (C), LED225.K (C), LED226.K (C), LED227.K (C), LED228.K (C), LED229.K (C), LED230.K (C), LED231.K (C), LED232.K (C), LED233.K (C), LED234.K (C), LED235.K (C), LED236.K (C), LED237.K (C), LED238.K (C), LED239.K (C), LED240.K (C)
F3: JP4.6, LED49.K (C), LED50.K (C), LED51.K (C), LED52.K (C), LED53.K (C), LED54.K (C), LED55.K (C), LED56.K (C), LED57.K (C), LED58.K (C), LED59.K (C), LED60.K (C), LED61.K (C), LED62.K (C), LED63.K (C), LED64.K (C), LED65.K (C), LED66.K (C), LED67.K (C), LED68.K (C), LED69.K (C), LED70.K (C), LED71.K (C), LED72.K (C), LED241.K (C), LED242.K (C), LED243.K (C), LED244.K (C), LED245.K (C), LED246.K (C), LED247.K (C), LED248.K (C), LED249.K (C), LED250.K (C), LED251.K (C), LED252.K (C), LED253.K (C), LED254.K (C), LED255.K (C), LED256.K (C), LED257.K (C), LED258.K (C), LED259.K (C), LED260.K (C), LED261.K (C), LED262.K (C), LED263.K (C), LED264.K (C)
F4: JP4.5, LED73.K (C), LED74.K (C), LED75.K (C), LED76.K (C), LED77.K (C), LED78.K (C), LED79.K (C), LED80.K (C), LED81.K (C), LED82.K (C), LED83.K (C), LED84.K (C), LED85.K (C), LED86.K (C), LED87.K (C), LED88.K (C), LED89.K (C), LED90.K (C), LED91.K (C), LED92.K (C), LED93.K (C), LED94.K (C), LED95.K (C), LED96.K (C), LED265.K (C), LED266.K (C), LED267.K (C), LED268.K (C), LED269.K (C), LED270.K (C), LED271.K (C), LED272.K (C), LED273.K (C), LED274.K (C), LED275.K (C), LED276.K (C), LED277.K (C), LED278.K (C), LED279.K (C), LED280.K (C), LED281.K (C), LED282.K (C), LED283.K (C), LED284.K (C), LED285.K (C), LED286.K (C), LED287.K (C), LED288.K (C)
F5: JP4.4, LED97.K (C), LED98.K (C), LED99.K (C), LED100.K (C), LED101.K (C), LED102.K (C), LED103.K (C), LED104.K (C), LED105.K (C), LED106.K (C), LED107.K (C), LED108.K (C), LED109.K (C), LED110.K (C), LED111.K (C), LED112.K (C), LED113.K (C), LED114.K (C), LED115.K (C), LED116.K (C), LED117.K (C), LED118.K (C), LED119.K (C), LED120.K (C), LED289.K (C), LED290.K (C), LED291.K (C), LED292.K (C), LED293.K (C), LED294.K (C), LED295.K (C), LED296.K (C), LED297.K (C), LED298.K (C), LED299.K (C), LED300.K (C), LED301.K (C), LED302.K (C), LED303.K (C), LED304.K (C), LED305.K (C), LED306.K (C), LED307.K (C), LED308.K (C), LED309.K (C), LED310.K (C), LED311.K (C), LED312.K (C)
F6: JP4.3, LED121.K (C), LED122.K (C), LED123.K (C), LED124.K (C), LED125.K (C), LED126.K (C), LED127.K (C), LED128.K (C), LED129.K (C), LED130.K (C), LED131.K (C), LED132.K (C), LED133.K (C), LED134.K (C), LED135.K (C), LED136.K (C), LED137.K (C), LED138.K (C), LED139.K (C), LED140.K (C), LED141.K (C), LED142.K (C), LED143.K (C), LED144.K (C), LED313.K (C), LED314.K (C), LED315.K (C), LED316.K (C), LED317.K (C), LED318.K (C), LED319.K (C), LED320.K (C), LED321.K (C), LED322.K (C), LED323.K (C), LED324.K (C), LED325.K (C), LED326.K (C), LED327.K (C), LED328.K (C), LED329.K (C), LED330.K (C), LED331.K (C), LED332.K (C), LED333.K (C), LED334.K (C), LED335.K (C), LED336.K (C)
F7: JP4.2, LED145.K (C), LED146.K (C), LED147.K (C), LED148.K (C), LED149.K (C), LED150.K (C), LED151.K (C), LED152.K (C), LED153.K (C), LED154.K (C), LED155.K (C), LED156.K (C), LED157.K (C), LED158.K (C), LED159.K (C), LED160.K (C), LED161.K (C), LED162.K (C), LED163.K (C), LED164.K (C), LED165.K (C), LED166.K (C), LED167.K (C), LED168.K (C), LED337.K (C), LED338.K (C), LED339.K (C), LED340.K (C), LED341.K (C), LED342.K (C), LED343.K (C), LED344.K (C), LED345.K (C), LED346.K (C), LED347.K (C), LED348.K (C), LED349.K (C), LED350.K (C), LED351.K (C), LED352.K (C), LED353.K (C), LED354.K (C), LED355.K (C), LED356.K (C), LED357.K (C), LED358.K (C), LED359.K (C), LED360.K (C)
F8: JP4.1, LED169.K (C), LED170.K (C), LED171.K (C), LED172.K (C), LED173.K (C), LED174.K (C), LED175.K (C), LED176.K (C), LED177.K (C), LED178.K (C), LED179.K (C), LED180.K (C), LED181.K (C), LED182.K (C), LED183.K (C), LED184.K (C), LED185.K (C), LED186.K (C), LED187.K (C), LED188.K (C), LED189.K (C), LED190.K (C), LED191.K (C), LED192.K (C), LED361.K (C), LED362.K (C), LED363.K (C), LED364.K (C), LED365.K (C), LED366.K (C), LED367.K (C), LED368.K (C), LED369.K (C), LED370.K (C), LED371.K (C), LED372.K (C), LED373.K (C), LED374.K (C), LED375.K (C), LED376.K (C), LED377.K (C), LED378.K (C), LED379.K (C), LED380.K (C), LED381.K (C), LED382.K (C), LED383.K (C), LED384.K (C)

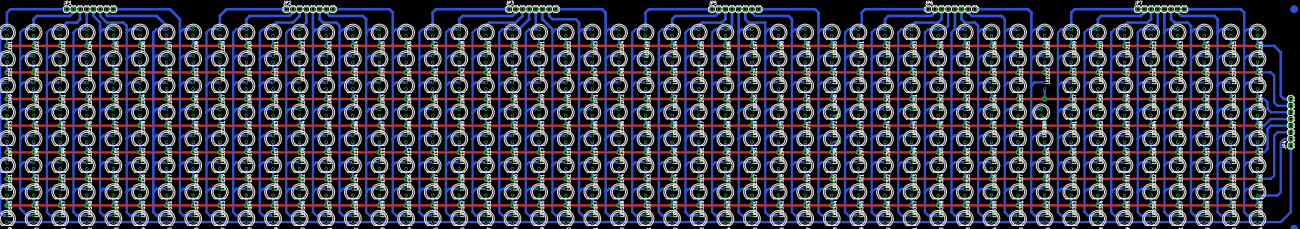
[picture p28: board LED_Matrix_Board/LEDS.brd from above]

Board: 2 copper layers, 391 parts (1 on the bottom side), 56 nets.

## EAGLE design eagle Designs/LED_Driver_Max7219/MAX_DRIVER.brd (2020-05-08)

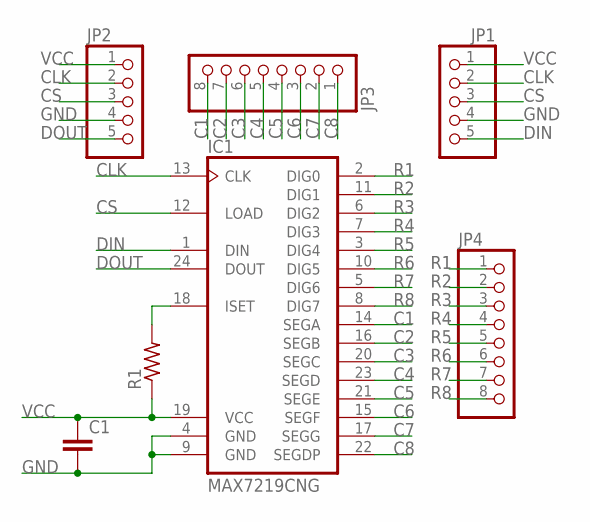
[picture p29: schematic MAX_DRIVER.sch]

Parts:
C1: C-EU025-025X050; C025-025X050
IC1: MAX7219CNG; DIL24-3
JP1, JP2: PINHD-1X5; 1X05
JP3, JP4: PINHD-1X8; 1X08
R1: R-US_M1206; M1206

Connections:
C1: IC1.14 (SEGA), JP3.8
C2: IC1.16 (SEGB), JP3.7
C3: IC1.20 (SEGC), JP3.6
C4: IC1.23 (SEGD), JP3.5
C5: IC1.21 (SEGE), JP3.4
C6: IC1.15 (SEGF), JP3.3
C7: IC1.17 (SEGG), JP3.2
C8: IC1.22 (SEGDP), JP3.1
CLK: IC1.13 (CLK), JP1.2, JP2.2
CS: IC1.12 (LOAD), JP1.3, JP2.3
DIN: IC1.1 (DIN), JP1.5
DOUT: IC1.24 (DOUT), JP2.5
GND: C1.2, IC1.4 (GND), IC1.9 (GND), JP1.4, JP2.4
unnamed: IC1.18 (ISET), R1.2
R1: IC1.2 (DIG0), JP4.1
R2: IC1.11 (DIG1), JP4.2
R3: IC1.6 (DIG2), JP4.3
R4: IC1.7 (DIG3), JP4.4
R5: IC1.3 (DIG4), JP4.5
R6: IC1.10 (DIG5), JP4.6
R7: IC1.5 (DIG6), JP4.7
R8: IC1.8 (DIG7), JP4.8
VCC: C1.1, IC1.19 (VCC), JP1.1, JP2.1, R1.1

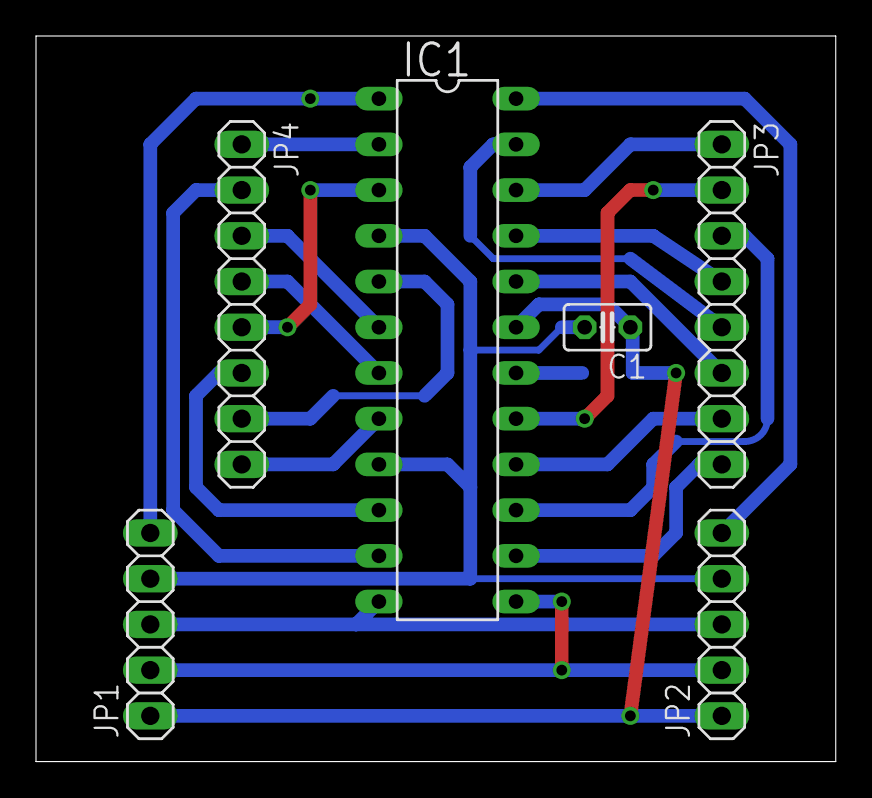
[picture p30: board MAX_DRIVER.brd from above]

Board: 2 copper layers, 44.4 x 40.3 mm, 7 parts (1 on the bottom side), 23 nets.

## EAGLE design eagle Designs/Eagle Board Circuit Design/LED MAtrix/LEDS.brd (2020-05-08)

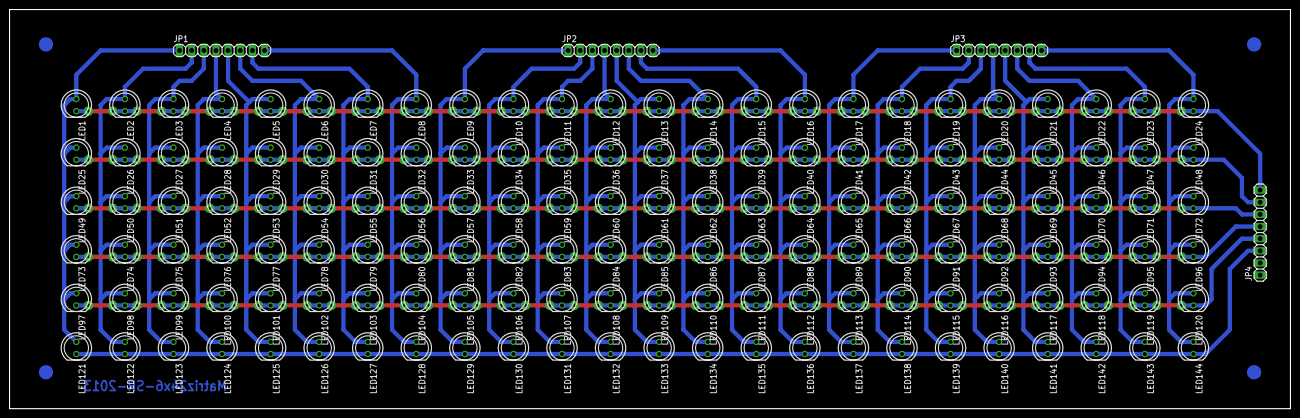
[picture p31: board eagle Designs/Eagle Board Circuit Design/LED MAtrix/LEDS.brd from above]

Board: 2 copper layers, 267.9 x 83.5 mm, 148 parts (0 on the bottom side), 30 nets.

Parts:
JP1, JP2, JP3, JP4: 1X08
LED1, LED2, LED3, LED4, LED5, LED6, LED7, LED8, LED9, LED10, LED11, LED12, LED13, LED14, LED15, LED16, LED17, LED18, LED19, LED20, LED21, LED22, LED23, LED24, LED25, LED26, LED27, LED28, LED29, LED30, LED31, LED32, LED33, LED34, LED35, LED36, LED37, LED38, LED39, LED40, LED41, LED42, LED43, LED44, LED45, LED46, LED47, LED48, LED49, LED50, LED51, LED52, LED53, LED54, LED55, LED56, LED57, LED58, LED59, LED60, LED61, LED62, LED63, LED64, LED65, LED66, LED67, LED68, LED69, LED70, LED71, LED72, LED73, LED74, LED75, LED76, LED77, LED78, LED79, LED80, LED81, LED82, LED83, LED84, LED85, LED86, LED87, LED88, LED89, LED90, LED91, LED92, LED93, LED94, LED95, LED96, LED97, LED98, LED99, LED100, LED101, LED102, LED103, LED104, LED105, LED106, LED107, LED108, LED109, LED110, LED111, LED112, LED113, LED114, LED115, LED116, LED117, LED118, LED119, LED120, LED121, LED122, LED123, LED124, LED125, LED126, LED127, LED128, LED129, LED130, LED131, LED132, LED133, LED134, LED135, LED136, LED137, LED138, LED139, LED140, LED141, LED142, LED143, LED144: LED5MM

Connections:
C1: JP1.1, LED1.A, LED25.A, LED49.A, LED73.A, LED97.A, LED121.A
C2: JP1.2, LED2.A, LED26.A, LED50.A, LED74.A, LED98.A, LED122.A
C3: JP1.3, LED3.A, LED27.A, LED51.A, LED75.A, LED99.A, LED123.A
C4: JP1.4, LED4.A, LED28.A, LED52.A, LED76.A, LED100.A, LED124.A
C5: JP1.5, LED5.A, LED29.A, LED53.A, LED77.A, LED101.A, LED125.A
C6: JP1.6, LED6.A, LED30.A, LED54.A, LED78.A, LED102.A, LED126.A
C7: JP1.7, LED7.A, LED31.A, LED55.A, LED79.A, LED103.A, LED127.A
C8: JP1.8, LED8.A, LED32.A, LED56.A, LED80.A, LED104.A, LED128.A
C9: JP2.1, LED9.A, LED33.A, LED57.A, LED81.A, LED105.A, LED129.A
C10: JP2.2, LED10.A, LED34.A, LED58.A, LED82.A, LED106.A, LED130.A
C11: JP2.3, LED11.A, LED35.A, LED59.A, LED83.A, LED107.A, LED131.A
C12: JP2.4, LED12.A, LED36.A, LED60.A, LED84.A, LED108.A, LED132.A
C13: JP2.5, LED13.A, LED37.A, LED61.A, LED85.A, LED109.A, LED133.A
C14: JP2.6, LED14.A, LED38.A, LED62.A, LED86.A, LED110.A, LED134.A
C15: JP2.7, LED15.A, LED39.A, LED63.A, LED87.A, LED111.A, LED135.A
C16: JP2.8, LED16.A, LED40.A, LED64.A, LED88.A, LED112.A, LED136.A
C17: JP3.1, LED17.A, LED41.A, LED65.A, LED89.A, LED113.A, LED137.A
C18: JP3.2, LED18.A, LED42.A, LED66.A, LED90.A, LED114.A, LED138.A
C19: JP3.3, LED19.A, LED43.A, LED67.A, LED91.A, LED115.A, LED139.A
C20: JP3.4, LED20.A, LED44.A, LED68.A, LED92.A, LED116.A, LED140.A
C21: JP3.5, LED21.A, LED45.A, LED69.A, LED93.A, LED117.A, LED141.A
C22: JP3.6, LED22.A, LED46.A, LED70.A, LED94.A, LED118.A, LED142.A
C23: JP3.7, LED23.A, LED47.A, LED71.A, LED95.A, LED119.A, LED143.A
C24: JP3.8, LED24.A, LED48.A, LED72.A, LED96.A, LED120.A, LED144.A
F1: JP4.8, LED1.K, LED2.K, LED3.K, LED4.K, LED5.K, LED6.K, LED7.K, LED8.K, LED9.K, LED10.K, LED11.K, LED12.K, LED13.K, LED14.K, LED15.K, LED16.K, LED17.K, LED18.K, LED19.K, LED20.K, LED21.K, LED22.K, LED23.K, LED24.K
F2: JP4.7, LED25.K, LED26.K, LED27.K, LED28.K, LED29.K, LED30.K, LED31.K, LED32.K, LED33.K, LED34.K, LED35.K, LED36.K, LED37.K, LED38.K, LED39.K, LED40.K, LED41.K, LED42.K, LED43.K, LED44.K, LED45.K, LED46.K, LED47.K, LED48.K
F3: JP4.6, LED49.K, LED50.K, LED51.K, LED52.K, LED53.K, LED54.K, LED55.K, LED56.K, LED57.K, LED58.K, LED59.K, LED60.K, LED61.K, LED62.K, LED63.K, LED64.K, LED65.K, LED66.K, LED67.K, LED68.K, LED69.K, LED70.K, LED71.K, LED72.K
F4: JP4.5, LED73.K, LED74.K, LED75.K, LED76.K, LED77.K, LED78.K, LED79.K, LED80.K, LED81.K, LED82.K, LED83.K, LED84.K, LED85.K, LED86.K, LED87.K, LED88.K, LED89.K, LED90.K, LED91.K, LED92.K, LED93.K, LED94.K, LED95.K, LED96.K
F5: JP4.4, LED97.K, LED98.K, LED99.K, LED100.K, LED101.K, LED102.K, LED103.K, LED104.K, LED105.K, LED106.K, LED107.K, LED108.K, LED109.K, LED110.K, LED111.K, LED112.K, LED113.K, LED114.K, LED115.K, LED116.K, LED117.K, LED118.K, LED119.K, LED120.K
F6: JP4.3, LED121.K, LED122.K, LED123.K, LED124.K, LED125.K, LED126.K, LED127.K, LED128.K, LED129.K, LED130.K, LED131.K, LED132.K, LED133.K, LED134.K, LED135.K, LED136.K, LED137.K, LED138.K, LED139.K, LED140.K, LED141.K, LED142.K, LED143.K, LED144.K

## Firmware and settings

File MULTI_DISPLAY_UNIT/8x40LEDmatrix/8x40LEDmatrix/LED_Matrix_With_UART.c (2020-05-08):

/*
  Project: Scrolling message on LED dot matrix display
  MCU: PIC16F1847 @ 16.0 MHz
  Copyright @ Rajendra Bhatt
  Apr 14, 2012
*/

// Define 74HC595 connections.

 sbit Serial_Data at RA0_bit;
 sbit SH_Clk at RA1_bit;
 sbit ST_Clk at RA2_bit;

 unsigned short Buffer[8][5] = {
                              {0,0,0,0,0},
                              {0,0,0,0,0},
                              {0,0,0,0,0},
                              {0,0,0,0,0},
                              {0,0,0,0,0},
                              {0,0,0,0,0},
                              {0,0,0,0,0},
                              {0,0,0,0,0}
                             };

unsigned int speed, StringLength;
unsigned short i, l, k, row, scroll, temp, shift_step=1;
unsigned short m, SerialConnect=0, UserIP = 0;

const unsigned char default_message[]="THIS IS A DEMONSTRATION OF AN 8X40 LED MATRIX DISPLAY USING \
SHIFT REGISTERS AND PIC16F1847 MICROCONTROLLER. FOR MORE DETAILS VISIT \
WWW.EMBEDDED-LAB.COM.    ";

char message[250], index;

void Send_Data(unsigned short rw){
 unsigned short Mask, t, num, Flag;
 for (num = 0; num < 5; num++) {
  Mask = 0x01;
  for (t=0; t<8; t++){
   Flag = Buffer[rw][num] & Mask;
   if(Flag==0) Serial_Data = 0;
   else Serial_Data = 1;
   SH_Clk = 1;
   SH_Clk = 0;
   Mask = Mask << 1;
  }
  }

  // Apply clock on ST_Clk
  ST_Clk = 1;
  ST_Clk = 0;

}

/* CharData is a two dimensional constant array that holds the 8-bit column values of
   individual rows for ASCII characters on a 8x8 matrix format.
*/
const unsigned short CharData[][8] ={
{0b00000000, 0b00000000, 0b00000000, 0b00000000, 0b00000000, 0b00000000, 0b00000000, 0b00000000},
{0b00000100, 0b00000100, 0b00000100, 0b00000100, 0b00000100, 0b00000100, 0b00000000, 0b00000100},
{0b00001010, 0b00001010, 0b00001010, 0b00000000, 0b00000000, 0b00000000, 0b00000000, 0b00000000},
{0b00000000, 0b00001010, 0b00011111, 0b00001010, 0b00011111, 0b00001010, 0b00011111, 0b00001010},
{0b00000111, 0b00001100, 0b00010100, 0b00001100, 0b00000110, 0b00000101, 0b00000110, 0b00011100},
{0b00011001, 0b00011010, 0b00000010, 0b00000100, 0b00000100, 0b00001000, 0b00001011, 0b00010011},
{0b00000110, 0b00001010, 0b00010010, 0b00010100, 0b00001001, 0b00010110, 0b00010110, 0b00001001},
{0b00000100, 0b00000100, 0b00000100, 0b00000000, 0b00000000, 0b00000000, 0b00000000, 0b00000000},
{0b00000010, 0b00000100, 0b00001000, 0b00001000, 0b00001000, 0b00001000, 0b00000100, 0b00000010},
{0b00001000, 0b00000100, 0b00000010, 0b00000010, 0b00000010, 0b00000010, 0b00000100, 0b00001000},
{0b00010101, 0b00001110, 0b00011111, 0b00001110, 0b00010101, 0b00000000, 0b00000000, 0b00000000},
{0b00000000, 0b00000000, 0b00000100, 0b00000100, 0b00011111, 0b00000100, 0b00000100, 0b00000000},
{0b00000000, 0b00000000, 0b00000000, 0b00000000, 0b00000000, 0b00000110, 0b00000100, 0b00001000},
{0b00000000, 0b00000000, 0b00000000, 0b00000000, 0b00001110, 0b00000000, 0b00000000, 0b00000000},
{0b00000000, 0b00000000, 0b00000000, 0b00000000, 0b00000000, 0b00000000, 0b00000000, 0b00000100},
{0b00000001, 0b00000010, 0b00000010, 0b00000100, 0b00000100, 0b00001000, 0b00001000, 0b00010000},
{0b00001110, 0b00010001, 0b00010011, 0b00010001, 0b00010101, 0b00010001, 0b00011001, 0b00001110},
{0b00000100, 0b00001100, 0b00010100, 0b00000100, 0b00000100, 0b00000100, 0b00000100, 0b00011111},
{0b00001110, 0b00010001, 0b00010001, 0b00000010, 0b00000100, 0b00001000, 0b00010000, 0b00011111},
{0b00001110, 0b00010001, 0b00000001, 0b00001110, 0b00000001, 0b00000001, 0b00010001, 0b00001110},
{0b00010000, 0b00010000, 0b00010100, 0b00010100, 0b00011111, 0b00000100, 0b00000100, 0b00000100},
{0b00011111, 0b00010000, 0b00010000, 0b00011110, 0b00000001, 0b00000001, 0b00000001, 0b00011110},
{0b00000111, 0b00001000, 0b00010000, 0b00011110, 0b00010001, 0b00010001, 0b00010001, 0b00001110},
{0b00011111, 0b00000001, 0b00000001, 0b00000001, 0b00000010, 0b00000100, 0b00001000, 0b00010000},
{0b00001110, 0b00010001, 0b00010001, 0b00001110, 0b00010001, 0b00010001, 0b00010001, 0b00001110},
{0b00001110, 0b00010001, 0b00010001, 0b00001111, 0b00000001, 0b00000001, 0b00000001, 0b00000001},
{0b00000000, 0b00000100, 0b00000100, 0b00000000, 0b00000000, 0b00000100, 0b00000100, 0b00000000},
{0b00000000, 0b00000100, 0b00000100, 0b00000000, 0b00000000, 0b00000100, 0b00000100, 0b00001000},
{0b00000001, 0b00000010, 0b00000100, 0b00001000, 0b00001000, 0b00000100, 0b00000010, 0b00000001},
{0b00000000, 0b00000000, 0b00000000, 0b00011110, 0b00000000, 0b00011110, 0b00000000, 0b00000000},
{0b00010000, 0b00001000, 0b00000100, 0b00000010, 0b00000010, 0b00000100, 0b00001000, 0b00010000},
{0b00001110, 0b00010001, 0b00010001, 0b00000010, 0b00000100, 0b00000100, 0b00000000, 0b00000100},
{0b00001110, 0b00010001, 0b00010001, 0b00010101, 0b00010101, 0b00010001, 0b00010001, 0b00011110},
{0b00001110, 0b00010001, 0b00010001, 0b00010001, 0b00011111, 0b00010001, 0b00010001, 0b00010001},
{0b00011110, 0b00010001, 0b00010001, 0b00011110, 0b00010001, 0b00010001, 0b00010001, 0b00011110},
{0b00000111, 0b00001000, 0b00010000, 0b00010000, 0b00010000, 0b00010000, 0b00001000, 0b00000111},
{0b00011100, 0b00010010, 0b00010001, 0b00010001, 0b00010001, 0b00010001, 0b00010010, 0b00011100},
{0b00011111, 0b00010000, 0b00010000, 0b00011110, 0b00010000, 0b00010000, 0b00010000, 0b00011111},
{0b00011111, 0b00010000, 0b00010000, 0b00011110, 0b00010000, 0b00010000, 0b00010000, 0b00010000},
{0b00001110, 0b00010001, 0b00010000, 0b00010000, 0b00010111, 0b00010001, 0b00010001, 0b00001110},
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
};

void Delay_onesec(){
  Delay_ms(1000);
}
unsigned short Find_StrLength(){
  return strlen(message);
}

void Save_Message(){
  EEPROM_Write(0x00, 1);
  EEPROM_Write(0x01, StringLength);
  for(i=0; i<StringLength; i++){
    EEPROM_Write(i+2, message[i]);
  }
  EEPROM_Write(i+2, 32);
  EEPROM_Write(i+3, 32);
  EEPROM_Write(i+4, 32);
  EEPROM_Write(i+5, 32);
  UART1_Write(13); // Carriage Return
  UART1_Write(10); // Line Feed
  UART_Write_Text("MESSAGE SAVED!");
}

void ListenSerial(){
  unsigned char RxByte;
  UART_Write_Text("---- 8X40 LED Matrix Display ----");
  UART1_Write(13); // Carriage Return
  UART1_Write(10); // Line Feed
  UART_Write_Text("ARE YOU READY FOR YOUR INPUT? Y/N");
  Delay_onesec();
  Delay_onesec();
  Delay_onesec();
  if (UART1_Data_Ready()) {
    RxByte = UART1_Read();
    if(RxByte == 'Y') {
      UART1_Write(13); // Carriage Return
      UART1_Write(10); // Line Feed
      UART_Write_Text("Great! Always terminate your message with #");
      UART1_Write(13); // Carriage Return
      UART1_Write(10); // Line Feed
      UART_Write_Text("Waiting for your input (MAX. 250 char.) ...");
      while (!UART_Data_Ready());          // if data is received
      UART_Read_Text(message, "#", 250);    // reads text until '#' is found
      message[0] = ' ';
      StringLength = Find_StrLength();
      UART1_Write(13); // Carriage Return
      UART1_Write(10); // Line Feed
      UART_Write_Text("Message received. Now saving into EEPROM ...");
      Save_Message();
    }
  }
}

// Subroutine to load the stored message onto RAM
void Load_Data(){
 for (k=0; k<StringLength+4; k++){
  message[k] = EEPROM_Read(k+2);
 }
}

void main() {
 OSCCON = 0b01110000;  // 32 MHz internal
 ANSELA = 0b00000000;  // PORTA all digital pins
 ANSELB = 0b00000000;  // PORTB all digital pins
 TRISA  = 0b00100000;  // RA5 is input only
 TRISB  = 0b00000010;  // RB1 is UART Rx
 PORTB  = 0;
 UART1_Init(115200);
 Delay_ms(100);
 ListenSerial();       // Check for serial data receive
 TRISB  = 0b00000000;  // PORTB is now all output
 RCSTA  = 0x00;
 // Read first two EEPROM locations
 UserIP = EEPROM_Read(0x00);
 
 if(UserIP == 1) {
   StringLength = EEPROM_Read(0x01);
   Load_Data();  // Read stored data and save into RAM
 }
 else  StringLength = 156;

 do {
 for (k=0; k<StringLength+4; k++){
  for (scroll=0; scroll<(8/shift_step); scroll++) {
   for (row=0; row<8; row++){
     if(UserIP == 1) index = message[k];
     else index = default_message[k];
     temp = CharData[index-32][row];
     Buffer[row][4] = (Buffer[row][4] << Shift_Step) | (Buffer[row][3] >> (8-Shift_Step));
     Buffer[row][3] = (Buffer[row][3] << Shift_Step) | (Buffer[row][2] >> (8-Shift_Step));
     Buffer[row][2] = (Buffer[row][2] << Shift_Step) | (Buffer[row][1] >> (8-Shift_Step));
     Buffer[row][1] = (Buffer[row][1] << Shift_Step) | (Buffer[row][0] >> (8-Shift_Step));
     Buffer[row][0] = (Buffer[row][0] << Shift_Step)| (temp >> ((8-shift_step)-scroll*shift_step));
   }
   speed = 15;
   for(l=0; l<speed;l++){
     m = 1;
     for (i=0; i<8; i++) {
       Send_Data(i);
       LATB = m;
       m = m << 1;
       Delay_us(1000);
     }  // i
   } // l
  } // scroll
 } // k

} while(1);
}

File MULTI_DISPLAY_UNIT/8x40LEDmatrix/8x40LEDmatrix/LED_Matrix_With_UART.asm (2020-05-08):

_Send_Data:

;LED_Matrix_With_UART.c,35 :: 		void Send_Data(unsigned short rw){
;LED_Matrix_With_UART.c,37 :: 		for (num = 0; num < 5; num++) {
	CLRF       Send_Data_num_L0+0
L_Send_Data0:
	MOVLW      5
	SUBWF      Send_Data_num_L0+0, 0
	BTFSC      STATUS+0, 0
	GOTO       L_Send_Data1
;LED_Matrix_With_UART.c,38 :: 		Mask = 0x01;
	MOVLW      1
	MOVWF      Send_Data_Mask_L0+0
;LED_Matrix_With_UART.c,39 :: 		for (t=0; t<8; t++){
	CLRF       Send_Data_t_L0+0
L_Send_Data3:
	MOVLW      8
	SUBWF      Send_Data_t_L0+0, 0
	BTFSC      STATUS+0, 0
	GOTO       L_Send_Data4
;LED_Matrix_With_UART.c,40 :: 		Flag = Buffer[rw][num] & Mask;
	MOVLW      5
	MOVWF      R0
	MOVLW      0
	MOVWF      R1
	MOVF       FARG_Send_Data_rw+0, 0
	MOVWF      R4
	CLRF       R5
	CALL       _Mul_16x16_U+0
	MOVLW      _Buffer+0
	ADDWF      R0, 1
	MOVLW      hi_addr(_Buffer+0)
	ADDWFC     R1, 1
	MOVF       Send_Data_num_L0+0, 0
	ADDWF      R0, 0
	MOVWF      FSR0L
	MOVLW      0
	ADDWFC     R1, 0
	MOVWF      FSR0H
	MOVF       Send_Data_Mask_L0+0, 0
	ANDWF      INDF0+0, 0
	MOVWF      R1
;LED_Matrix_With_UART.c,41 :: 		if(Flag==0) Serial_Data = 0;
	MOVF       R1, 0
	XORLW      0
	BTFSS      STATUS+0, 2
	GOTO       L_Send_Data6
	BCF        RA0_bit+0, BitPos(RA0_bit+0)
	GOTO       L_Send_Data7
L_Send_Data6:
;LED_Matrix_With_UART.c,42 :: 		else Serial_Data = 1;
	BSF        RA0_bit+0, BitPos(RA0_bit+0)
L_Send_Data7:
;LED_Matrix_With_UART.c,43 :: 		SH_Clk = 1;
	BSF        RA1_bit+0, BitPos(RA1_bit+0)
;LED_Matrix_With_UART.c,44 :: 		SH_Clk = 0;
	BCF        RA1_bit+0, BitPos(RA1_bit+0)
;LED_Matrix_With_UART.c,45 :: 		Mask = Mask << 1;
	LSLF       Send_Data_Mask_L0+0, 1
;LED_Matrix_With_UART.c,39 :: 		for (t=0; t<8; t++){
	INCF       Send_Data_t_L0+0, 1
;LED_Matrix_With_UART.c,46 :: 		}
	GOTO       L_Send_Data3
L_Send_Data4:
;LED_Matrix_With_UART.c,37 :: 		for (num = 0; num < 5; num++) {
	INCF       Send_Data_num_L0+0, 1
;LED_Matrix_With_UART.c,47 :: 		}
	GOTO       L_Send_Data0
L_Send_Data1:
;LED_Matrix_With_UART.c,50 :: 		ST_Clk = 1;
	BSF        RA2_bit+0, BitPos(RA2_bit+0)
;LED_Matrix_With_UART.c,51 :: 		ST_Clk = 0;
	BCF        RA2_bit+0, BitPos(RA2_bit+0)
;LED_Matrix_With_UART.c,53 :: 		}
L_end_Send_Data:
	RETURN
; end of _Send_Data

_Delay_onesec:

;LED_Matrix_With_UART.c,156 :: 		void Delay_onesec(){
;LED_Matrix_With_UART.c,157 :: 		Delay_ms(1000);
	MOVLW      41
	MOVWF      R11
	MOVLW      150
	MOVWF      R12
	MOVLW      127
	MOVWF      R13
L_Delay_onesec8:
	DECFSZ     R13, 1
	GOTO       L_Delay_onesec8
	DECFSZ     R12, 1
	GOTO       L_Delay_onesec8
	DECFSZ     R11, 1
	GOTO       L_Delay_onesec8
;LED_Matrix_With_UART.c,158 :: 		}
L_end_Delay_onesec:
	RETURN
; end of _Delay_onesec

_Find_StrLength:

;LED_Matrix_With_UART.c,159 :: 		unsigned short Find_StrLength(){
;LED_Matrix_With_UART.c,160 :: 		return strlen(message);
	MOVLW      _message+0
	MOVWF      FARG_strlen_s+0
	MOVLW      hi_addr(_message+0)
	MOVWF      FARG_strlen_s+1
	CALL       _strlen+0
;LED_Matrix_With_UART.c,161 :: 		}
L_end_Find_StrLength:
	RETURN
; end of _Find_StrLength

_Save_Message:

;LED_Matrix_With_UART.c,163 :: 		void Save_Message(){
;LED_Matrix_With_UART.c,164 :: 		EEPROM_Write(0x00, 1);
	CLRF       FARG_EEPROM_Write_Address+0
	MOVLW      1
	MOVWF      FARG_EEPROM_Write_data_+0
	CALL       _EEPROM_Write+0
;LED_Matrix_With_UART.c,165 :: 		EEPROM_Write(0x01, StringLength);
	MOVLW      1
	MOVWF      FARG_EEPROM_Write_Address+0
	MOVF       _StringLength+0, 0
	MOVWF      FARG_EEPROM_Write_data_+0
	CALL       _EEPROM_Write+0
;LED_Matrix_With_UART.c,166 :: 		for(i=0; i<StringLength; i++){
	CLRF       _i+0
L_Save_Message9:
	MOVF       _StringLength+1, 0
	SUBLW      0
	BTFSS      STATUS+0, 2
	GOTO       L__Save_Message47
	MOVF       _StringLength+0, 0
	SUBWF      _i+0, 0
L__Save_Message47:
	BTFSC      STATUS+0, 0
	GOTO       L_Save_Message10
;LED_Matrix_With_UART.c,167 :: 		EEPROM_Write(i+2, message[i]);
	MOVLW      2
	ADDWF      _i+0, 0
	MOVWF      FARG_EEPROM_Write_Address+0
	MOVLW      _message+0
	MOVWF      R0
	MOVLW      hi_addr(_message+0)
	MOVWF      R1
	MOVF       _i+0, 0
	ADDWF      R0, 0
	MOVWF      FSR0L
	MOVLW      0
	ADDWFC     R1, 0
	MOVWF      FSR0H
	MOVF       INDF0+0, 0
	MOVWF      FARG_EEPROM_Write_data_+0
	CALL       _EEPROM_Write+0
;LED_Matrix_With_UART.c,166 :: 		for(i=0; i<StringLength; i++){
	INCF       _i+0, 1
;LED_Matrix_With_UART.c,168 :: 		}
	GOTO       L_Save_Message9
L_Save_Message10:
;LED_Matrix_With_UART.c,169 :: 		EEPROM_Write(i+2, 32);
	MOVLW      2
	ADDWF      _i+0, 0
	MOVWF      FARG_EEPROM_Write_Address+0
	MOVLW      32
	MOVWF      FARG_EEPROM_Write_data_+0
	CALL       _EEPROM_Write+0
;LED_Matrix_With_UART.c,170 :: 		EEPROM_Write(i+3, 32);
	MOVLW      3
	ADDWF      _i+0, 0
	MOVWF      FARG_EEPROM_Write_Address+0
	MOVLW      32
	MOVWF      FARG_EEPROM_Write_data_+0
	CALL       _EEPROM_Write+0
;LED_Matrix_With_UART.c,171 :: 		EEPROM_Write(i+4, 32);
	MOVLW      4
	ADDWF      _i+0, 0
	MOVWF      FARG_EEPROM_Write_Address+0
	MOVLW      32
	MOVWF      FARG_EEPROM_Write_data_+0
	CALL       _EEPROM_Write+0
;LED_Matrix_With_UART.c,172 :: 		EEPROM_Write(i+5, 32);
	MOVLW      5
	ADDWF      _i+0, 0
	MOVWF      FARG_EEPROM_Write_Address+0
	MOVLW      32
	MOVWF      FARG_EEPROM_Write_data_+0
	CALL       _EEPROM_Write+0
;LED_Matrix_With_UART.c,173 :: 		UART1_Write(13); // Carriage Return
	MOVLW      13
	MOVWF      FARG_UART1_Write_data_+0
	CALL       _UART1_Write+0
;LED_Matrix_With_UART.c,174 :: 		UART1_Write(10); // Line Feed
	MOVLW      10
	MOVWF      FARG_UART1_Write_data_+0
	CALL       _UART1_Write+0
;LED_Matrix_With_UART.c,175 :: 		UART_Write_Text("MESSAGE SAVED!");
	MOVLW      ?lstr1_LED_Matrix_With_UART+0
	MOVWF      FARG_UART_Write_Text_uart_text+0
	MOVLW      hi_addr(?lstr1_LED_Matrix_With_UART+0)
	MOVWF      FARG_UART_Write_Text_uart_text+1
	CALL       _UART_Write_Text+0
;LED_Matrix_With_UART.c,176 :: 		}
L_end_Save_Message:
	RETURN
; end of _Save_Message

_ListenSerial:
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

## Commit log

2020-05-08 Circuit Design & MATRIX board
    [LEDS.brd, LEDS.sch, MAX_DRIVER.brd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]
2020-05-08 Final Code & report
    [LED_Matrix_With_UART.cfg]
